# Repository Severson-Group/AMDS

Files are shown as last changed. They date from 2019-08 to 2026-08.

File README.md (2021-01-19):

# Advanced Motor Drive Sensing System (AMDS)

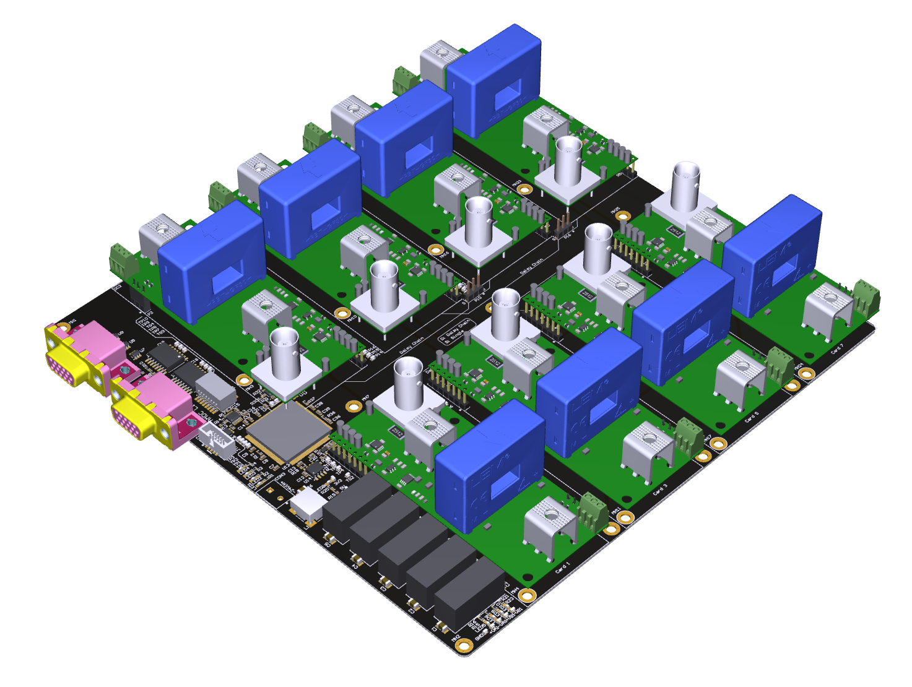
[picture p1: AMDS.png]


The AMDS is a hardware platform for sensing parameters such as currents and voltages in power electronic systems. 
The platform includes:

-  Sensor cards to measure [low voltage](./LowVoltageCard), [high voltage](./HighVoltageCard), and [currents](./CurrentCard).
-  A [mainboard](./Mainboard) that serves as a carrier board for upto 8 sensor cards.
-  SPI interface between the sensor cards and the mainboard.
-  Robust differential IO communication to transmit sensor data to an external controller such as the [AMDC](https://amdc.dev/).

## Documentation
Detailed documentaion for each sensor card and the mainboard are available in the respective folders.

## Repository Structure
Each sensor card and the mainboard have a corresponding folder in the root level of the repository. These folders are organized as follows:

- The `altium` sub-folder contains all files pertaining to schematics / board design in Altium Designer. These files are the latest working copy of the project.

- The `REVyyyymmdd*` sub-folder represents snapshots of the project that were used to produce a physical PCB. These directories contain the Gerber, Drill (Excellon format), Bill of Materials (XLS), and Schematic (PDF) files.

  - `REV` indicates a revision of design for manufacturing
  - `yyyymmdd` indicates the date on which design was frozen
  - `*` (letter) indicates which revision in sequence (A - first, B - second, etc.)
  
- The `docs` sub-folder contains documentation for the PCB.

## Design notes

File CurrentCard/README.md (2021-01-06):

# Current Card

The current card is a daughter card designed for the AMDS platform. This daughtercard plugs into the mainboard which then drives this card.

## Documentation

Documentation about the design of this daughter card is located in the [docs folder.](docs/)

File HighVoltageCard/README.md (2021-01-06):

# High Voltage Card

This folder contains the design files for the high voltage card which serves as a daugherboard for the AMDS mainboard. The high voltage card can measure differential voltages up to +/- 500 V.

The details of the implementation can be found in the [`docs`](docs/) folder.

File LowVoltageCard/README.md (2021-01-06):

# Low Voltage Card

This subfolder houses all the design files for the Low Voltage Card, a daughtercard designed for the AMDS platform. This daughtercard plugs into the mainboard which then drives this board's on-board ADC.

## Documentation

Read about the design of this daughtercard in the [docs folder...](docs/)

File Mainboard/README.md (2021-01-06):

# Mainboard



The mainboard provides a single interface to multiple analog input PCBs (up to 8 daughtercards can be installed). The board features a microcontroller that operates ADCs on each daughter card and presents an isolated, high speed digital interface that can be connected to a digital system control board (this board is designed to connect directly to an expansion port of the [AMDC](https://github.com/severson-group/amdc-hardware)). Design features are implemented to minimize EMI and facilitate operation in an electric motor drive.

The details of the implementation can found in the [`docs/` folder](https://github.com/Severson-Group/SensorCard/blob/Motherboard_REVC/Motherboard/docs/README.md).

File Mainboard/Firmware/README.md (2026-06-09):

# Mainboard Firmware

The "mainboard" is part of the SensorCard platform. It can hold up to eight daughter cards, each of which contain a SPI ADC device. These ADCs are then sampled by the mainboard's MCU. The ADC samples are transmitted back to the AMDC so control algorithms can make use of the extra analog inputs. Several daughter card designs exist:

1. Current sense
2. High Voltage sense (for bus voltage levels)
3. Low Voltage sense (for +/- 10V levels)

This folder houses all the files needed to build the firmware which runs on the MCU on the mainboard PCB.

## Required Tools

To easily build this firmware and load it onto a mainboard, please install the following software on your host PC:

- [STM32CubeIDE](https://www.st.com/en/development-tools/stm32cubeide.html) -- the latest version is fine.

This tool is analogous to the Xilinx SDK tool (for the AMDC). It is effectively the Eclipse IDE but with customizations from ST. You can write all the C code here, compile it, flash the MCU, debug, etc.

## Development Steps

To develop code for STM32 processors:

### Testing / Debugging Code

1. Use the IDE to compile your code and ensure there are no errors.
2. To flash the hardware, plug in a SWD debugger device to your PC + board (highly recommend [`STLINK-V3SET`](https://www.digikey.com/product-detail/en/stmicroelectronics/STLINK-V3SET/497-18216-ND/9636028))
3. Configure a debug session in the IDE
4. Run the debug sessions. This will flash the MCU and start the code (probably breakpoint at `main()`)

For more detailed instructions on programming the AMDS, please refer to the [AMDS Documentation](https://docs.amdc.dev/accessories/amds/index.html).

NOTE: The STM32 devices are typically programmed into non-volatile memory. Therefore, there is no seperate "flashing" step. Every time you upload code, it is permanantely stored on the processor. You can power cycle the device and your code will start running again.

## Mainboard Firmware Design

The mainboard firmware is fairly simple, yet very specialized for the application. Before changing *anything* in the code, make sure you understand how it works. Practically every line of the code is optimized for speed and efficiency! Using a multi-channel logic analyzer / oscilloscope is absolutely required when updating the mainboard firmware to validate code timing. Please refer to the [Firmware Architecture Documentation](https://docs.amdc.dev/accessories/amds/firmware/index.html) for more information.

**Do not blindly change the code.**

## Flashing Firmware to Mainboards with Alternative STM32F745ZG Processors

The firmware project provided in this repository is configured for a mainboard populated with a STM32F**765**ZG processor. This project configuration is incompatible with the alternative STM32F**745**ZG chip that is populated on some mainboard PCBs. Creating a new project targeting the alternative STM32F**745**ZG processor and loading in the provided source files is required. Here's how that's done.

### Create a new STM32 Project
1. Within STM32CubeIDE create a new `STM32 project` targeting the `STM32F745ZG` device with the following settings:
    - Targeted Language: `C`
    - Targeted Binary Type: `Executable`
    - Targeted Project Type: `STM32Cube`

### Replace Source Code
2. Open the file folder location of the newly created project 
3. Navigate to the `\Core\` directory and replace the `\Src` & `\Inc` folders with the ones provided in the AMDS repository
4. Navigate to the `\Drivers\STM32F7xx_HAL_Driver` directory and replace the `\Src` & `\Inc` folders with the ones provided in the AMDS repository
5. Within STM32CubeIDE refresh & build the project, no errors should be present

### Increase Compiler Optimization
6. In the `Project Explorer` pane on the left, right-click on the STM32Cube Project you created, and click on Properties
7. Expand `C/C++ Build` and click `Settings`
8. Find and click on `MCU GCC Compiler` > `Optimization`
9. Select the dropdown next for `Optimization Level` and change to `Optimize more (-O2)`
10. Select `Apply and Close`

### Flash Firmware to Mainboard
11. Select `Debug Configurations` under the `Run` menu at the top
12. Select the `Debugger` tab in the pop-up window
13. Change the `Frequency (kHz)` setting from `Auto` to `140`
14. Select `Apply` 

You are now ready to connect & flash the firmware to the STM32F**745**ZG processor equiped Mainboard!

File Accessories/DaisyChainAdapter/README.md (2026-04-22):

# AMDS Daisy Chain Adapter Board

This subfolder houses all the design files for the daisy chain adapter board used to operate the AMDS in a daisy-chained configuration.

## Documentation

Documentation about the design of this  board can be found in the [docs folder.](docs/)

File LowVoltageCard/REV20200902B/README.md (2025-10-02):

# Low Voltage Card REV20200902B

This folder contains the compiled design outputs for the Low Voltage Card. This includes the schematics, images of the PCB layout, the bill of materials (BOM), and the files needed to order fully populated boards from an online vendor.

## Board Parameters

| Question | Answer |
|---|---|
| Board Size | 3.575" x 1.465" |
| Number of Layers | 2 Layers |
| Double Sided | No |
| Surface Finish | Tin lead |
| Silkscreen | White |
| Material | FR-4, TG150 |
| Board Thickness | 1.6 mm |
| Min Trace Spacing | 0.15 mm (6 mil) |
| Min Hole Size | 0.38 mm (15 mil)|
| Number of Holes | 55 |
| Solder Mask | Black |
| HASL or ENIG | No |
| Finished Copper | 1 oz |

## Assembly Details

| Question | Answer |
|---|---|
| Unique Part Count[^1] | 20 |
| Number of Total Parts[^1] | 52 |
| Total SMT Part Count | 47 |
| Total Through-hole Part Count | 5 |
| Total Mechanical Screws[^2] | 2 |
| Total Mechanical Standoffs[^2] | 2 |
| BGA / QFN | No |

[^1]: This number does not include screws or standoffs. With screws and standoffs included, the unique part count is 22 and total parts is 56. Users are advised to not have their assembly vendor place screws and standoffs.

[^2]: There are screws and standoffs required for mounting this card to the mainboard. For details on what those components are, please refer to the [Main Board](../../Mainboard/REV20200920D/README.md)

## Bill of Materials
The [Bill of Materials (BOM)](low-voltage-card-bom.csv) contains components for 1 board. If users of this repo discover that any components are unavailable, please maintain an `alternate-components.md` file in this folder that lists approved alternates.

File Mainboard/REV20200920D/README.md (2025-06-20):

# AMDS REV20200920D

This folder contains the compiled design outputs for AMDS REV D. This includes the schematics, images of the PCB layout, the bill of materials (BOM), and the files needed to order fully populated boards from an online vendor.

## Board Parameters

| Question | Answer |
|---|---|
| Board Size | 8" x 8" |
| Number of Layers | 4 Layers |
| Double Sided | No |
| Surface Finish | Tin lead |
| Silkscreen | White |
| Material | FR-4, TG150 |
| Board Thickness | 1.6 mm |
| Min Trace Spacing | 0.15 mm (6 mil) |
| Min Hole Size | 0.35 mm (14 mil)|
| Number of Holes | 569 |
| Solder Mask | Black |
| HASL or ENIG | No |
| Finished Copper | 1 oz |

## Assembly Details

| Question | Answer |
|---|---|
| Unique Part Count[^1] | 42 |
| Number of Total Parts[^1] | 199 |
| Total SMT Part Count | 146 |
| Total Through-hole Part Count | 53 |
| Total Mechanical Screws[^2] | 43 |
| Total Mechanical Standoffs[^3] | 27 |
| BGA / QFN | No |

[^1]: This number does not include screws or standoffs. With screws and standoffs included, the unique part count is 45 and total parts is 269. Users are advised to not have their assembly vendor place screws and standoffs.

[^2]: There are a total of 43 screws per board, where 11 screws will be used for the mainboard mounting holes, and 32 screws will be used for mounting the 8 sensor cards.

[^3]: There are a total of 27 standoffs per board, where 11 standoffs will be used for the mainboard mounting holes, and 16 standoffs will be used for mounting all the 8 sensor cards.

## Bill of Materials
The [Bill of Materials (BOM)](mainboard-bom.csv) contains components for 1 board. If users of this repo discover that any components are unvailable, please maintain an `alternate-components.md` file in this folder that lists approved alternates. 

Note that several resistors are indicated with a value of `DNP` (do not populate). These are components that should not be soldered onto the board in standard builds to avoid ground loops and allow for daisy chain operation[^4].

## Sensor Card Mounting
The [Bill of Materials (BOM)](mainboard-bom.csv) and [Schematic](mainboard-sch.pdf)[^5] contain the screws and standoffs required to mount 8 sensor cards to 1 board.

[^4]: An audit of the DNP components is discussed in [this GitHub issue](https://github.com/Severson-Group/AMDS/issues/63).

[^5]: Note that the large amount of mounting hardware on this schematic means that the default export PDF from Altium results in a large file size. For this reason, developers are advised to use Adobe to compress the schematic file before committing to the repo. The `Low` compression setting is recommended.

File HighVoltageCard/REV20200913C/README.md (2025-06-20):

# High Voltage Card REV20200913C

This folder contains the compiled design outputs for the High Voltage Card. This includes the schematics, images of the PCB layout, the bill of materials (BOM), and the files needed to order fully populated boards from an online vendor.

## Board Parameters

| Question | Answer |
|---|---|
| Board Size | 3.57" x 1.46" |
| Number of Layers | 2 Layers |
| Double Sided | No |
| Surface Finish | Tin lead |
| Silkscreen | White |
| Material | FR-4, TG150 |
| Board Thickness | 1.6 mm |
| Min Trace Spacing | 0.15 mm (6 mil) |
| Min Hole Size | 0.40 mm (16 mil)|
| Number of Holes | 54 |
| Solder Mask | Black |
| HASL or ENIG | No |
| Finished Copper | 1 oz |

## Assembly Details

| Question | Answer |
|---|---|
| Unique Part Count[^1] | 23 |
| Number of Total Parts[^1] | 42 |
| Total SMT Part Count | 27 |
| Total Through-hole Part Count | 15 |
| Total Mechanical Screws[^2] | 2 |
| Total Mechanical Standoffs[^2] | 2 |
| BGA / QFN | No |

## Bill of Materials
The [Bill of Materials (BOM)](high-voltage-sensor-bom.csv) contains components for 1 board. If users of this repo discover that any components are unavailable, please maintain an `alternate-components.md` file in this folder that lists approved alternates.

[^1]: This number does not include screws or standoffs. With screws and standoffs included, the unique part count is 25 and total parts is 46. Users are advised to not have their assembly vendor place screws and standoffs.

[^2]: There are screws and standoffs required for mounting this card to the mainboard. For details on what those components are, please refer to the [Main Board](../../Mainboard/REV20200920D/README.md)

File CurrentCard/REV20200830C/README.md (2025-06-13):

# Current Card REV20200830C

This folder contains the compiled design outputs for the Current Card. This includes the schematics, images of the PCB layout, the bill of materials (BOM), and the files needed to order fully populated boards from an online vendor.

## Board Parameters

| Question | Answer |
|---|---|
| Board Size | 3.58" x 1.47" |
| Number of Layers | 2 Layers |
| Double Sided | No |
| Surface Finish | Tin lead |
| Silkscreen | White |
| Material | FR-4, TG150 |
| Board Thickness | 1.6 mm |
| Min Trace Spacing | 0.15 mm (6 mil) |
| Min Hole Size | 0.40 mm (16 mil)|
| Number of Holes | 58 |
| Solder Mask | Black |
| HASL or ENIG | No |
| Finished Copper | 1 oz |

## Assembly Details

| Question | Answer |
|---|---|
| Unique Part Count[^1] | 21 |
| Number of Total Parts[^1] | 41 |
| Total SMT Part Count | 27 |
| Total Through-hole Part Count | 14 |
| Total Mechanical Screws[^2] | 4 |
| Total Mechanical Standoffs[^2] | 2 |
| BGA / QFN | No |

## Bill of Materials
The [Bill of Materials (BOM)](current-sensor-bom.csv) contains components for 1 board. If users of this repo discover that any components are unavailable, please maintain an `alternate-components.md` file in this folder that lists approved alternates.

[^1]: This number does not include screws or standoffs. With screws and standoffs included, the unique part count is 23 and total parts is 45. Users are advised to not have their assembly vendor place screws and standoffs.

[^2]: There are screws and standoffs required for mounting this card to the mainboard. For details on what those components are, please refer to the [Main Board](../../Mainboard/REV20200920D/README.md)

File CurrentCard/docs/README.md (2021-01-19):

# Current Card

This document describes the design considerations and implementation details for the current card. 
A block diagram is presented and each component is discussed in detail. Specifications of each component are provided based on the datasheet.

## Relevant Hardware Versions

REV C

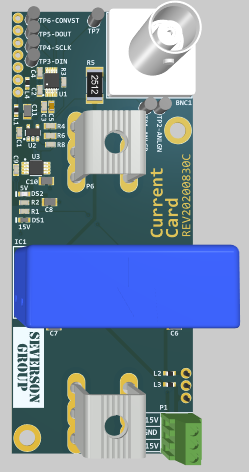
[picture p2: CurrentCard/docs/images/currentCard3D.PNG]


## Design Requirements and Considerations

The current measurement card was designed to the following specifications:

1. Current measurement range of +/- 55A (rms)
2. Noise immunity
3. Quick adjustment of the sensing range
4. High sensor bandwidth
5. SPI output to interface with the sensor motherboard

## Block Diagram
The high level block diagram of the current sensor card is shown below:



### Current Sensor
LEM LA 55-P current sensor is selected for this design, as it is the only sensor available from LEM with an open aperture and PC pins that can measure +/-55A. 
The open aperture was a requirement as it allows for the range to be easily scaled down just by adding turns to the primary. 
The LA 55-P is a closed loop compensated hall effect transducer that has an accuracy of +/-0.65% and linearity of <0.15% which is quite good compared to other sensors from LEM. 
It has an excellent bandwidth of 200khz and a low impedance current output that is inherently more immune to noise than a high impedance voltage output. 

### Burden Resistor (_R_<sub>_BURDEN_</sub>)
A burden resistor (`R5`) is used to convert the current output of the sensor to a voltage. For a sensing range of 70A, the burden resistance, _R_<sub>_BURDEN_</sub> was calculated using the following equation

_V_<sub>_BURDEN_</sub>  = _I_<sub>_PRIMARY_</sub>(_N_<sub>2</sub>/_N_<sub>1</sub>)_R_<sub>_BURDEN_</sub>

_R_<sub>_BURDEN_</sub>  = (10 V/70 A)*(1000/1) = 143Ω 

The LA 55-P datasheet specifies the burden resistor value must be between 135Ω and 155Ω so a 150Ω resistor was selected.

### Current Sensor Gain
The LA 55P has a conversion ratio of _N_<sub>1</sub>:_N_<sub>2</sub> = 1:1000, where _N_<sub>1</sub> is the primary turns (user configurable) and _N_<sub>2</sub> is the secondary turns. With the chosen _R_<sub>_BURDEN_</sub> and _N_<sub>1</sub> = 1, the current sense circuitry has a current - voltage gain of 1/7 [V/A]. 
To sense lower current, multiple number of primary turns can be added, without the need to modify any other parts of the circuit. As an example, to sense currents in the range of +/- 7 A, _N_<sub>1</sub> = 10 can be used, without modifying rest of the circuit.

### Op Amp Stage
The voltage across the burden resistor is a bipolar signal (voltage span includes both positive and negative voltages).
A non-inverting level translation circuit is designed using Op Amps as shown here:



This circuit is used to translate the voltage across the burden resistor, which is bipolar, to the ADC input range of 0-4.5V. The resistor values can be calculated analytically. However, the algebra gets quite complicated. Hence it was computed using TI analog engineer's calculator. 

**Note:** As the op-amp output voltage approaches the supply rails, it tends to distort and behave nonlinearly so the output voltage is limited to actually be 0.2V to 4.5V

### Voltage Reference (LDO)
The voltage reference, _V_<sub>_REF_</sub> is needed for the ADC. As 5V is readily available, and the LDO will have a minimum drop out voltage,  _V_<sub>_REF_</sub> = 4.5V was chosen. The LDO selected was `REF5045` from Texas Instruments, which can take a 5V input and provide a 4.5V reference output. This has an accuracy of 0.1% and low noise of 3μVpp/V.

### First Order Anti-Aliasing Filter
A first order RC filter is implemented on the output of the op amp circuit. The cutoff frequency was set at 48kHz and the following equations was used for the computation:

_f_<sub>c</sub> = 1 / (2 π _RC_)

**Note:** The cutoff frequency can easily be changed by swapping out `R3`.

### Analog to Digital Converter
A single-ended ADC was selected. The ADC used is the Texas Instruments ADS8860. It is pseudo-differential input, SPI output, SAR ADC. 
The maximum data throughput for a single chip is 1 MSPS but decreases by a factor of N for N devices in the daisy-chain. 
The input voltage range is 0-4.5V. The positive input pin of the ADC `AINP` is connected to the output of the low pass filter, and the negative input pin `AINN` is connected to `GND`.

**Note:** The different stages of the current sensor card described above convert the input current into a voltage in the range of 0.2V - 4.5V. Therefore, 0 input current corresponds to 2.35V at the ADC input. The positive peak corresponds to 4.5V and the negative peak corresponds to 0.2V.

### Connectors
- There are two screw terminals `P5` and `P6` to connect the conductor in which the current is to be measured
- A screw terminal block `P1` is used to connect the +-15V supply for the current sensor
- A BNC terminal is available to directly measure the output across the burden resistor _R_<sub>_BURDEN_</sub>

### Footprints
A user may want to change some of the passive components based on the range required and the RC filter cutoff frequency desired. The footprints of passive components that may need to be replaced i.e, the burden resistor (`R5`), the resistors in the Op Amp stage, and the RC filter components is provided here for quick reference. Note that these footprints are imperial codes and **not metric codes**.

| Component | Footprint |
| ---- | ----- |
| R3 |  0603|
| R4 | 0603 |
| R5 | 2512 |
| R6 | 0603 |
| R8 | 0603 |
| C5 | 0603 |

## Datasheets
- [Current Sensor](../datasheets/LA55P_Current%20Sensor.pdf)
- [Op Amp](../datasheets/OPA320_OpAmp.pdf)
- [Voltage Reference (LDO)](../datasheets/REF5045_LDO.pdf)
- [Analog to Digital Converter](../datasheets/ADS_8860_ADC.pdf)

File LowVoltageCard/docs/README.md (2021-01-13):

# Low Voltage Card

This document describes the design considerations and implementation details for the low voltage card, which serves as a daughtercard for the AMDS mainboard.

## Relevant Hardware Versions

- REV A
- REV B

## Design Requirements and Considerations

The analog input card was designed to the following specifications:

1. Analog input signal of +/- 10V
2. Truly differential input
3. High common-mode rejection ratio
4. ADC has various pin-compatible versions available (different sampling rates)

Since these requirements very closely mirror the analog inputs on the AMDC, a similar design is used. The reader can learn about the AMDC analog inputs by reading [its documentation](https://github.com/Severson-Group/AMDC-Hardware/blob/develop/docs/Analog.md). The same front-end analog conditioning circuitry is used. However, while the ADC is still a differential input device (like the AMDC), it is a different part. This analog input board has a single-channel 16-bit ADC that accepts differential inputs. The digital interface is standard SPI.

Various ADCs are available which are pin-compatible to the part designed into the PCB. This means that the user can select which one they want when they assemble the boards. The ADCs offer the same specs, but vary on the sample rate. More expensive ADCs provide a higher sample rate.

### Pin Compatible ADCs

The default ADC is **bolded** below, but any of the follow ADCs work with the design.

- 100 kSPS: ADS8867
- **400 kSPS: ADS8865**
- 680 kSPS: ADS8863
- 1000 kSPS: ADS8861

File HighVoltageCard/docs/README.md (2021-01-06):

# High Voltage Card

This document describes the design consideration and implementation details for the high voltage card, which serves as a daughter card for the AMDS mainboard.
A block diagram is presented and each component is discussed in detail. Specifications of each component are provided based on the datasheet.

## Relevant Hardware Versions

REV C

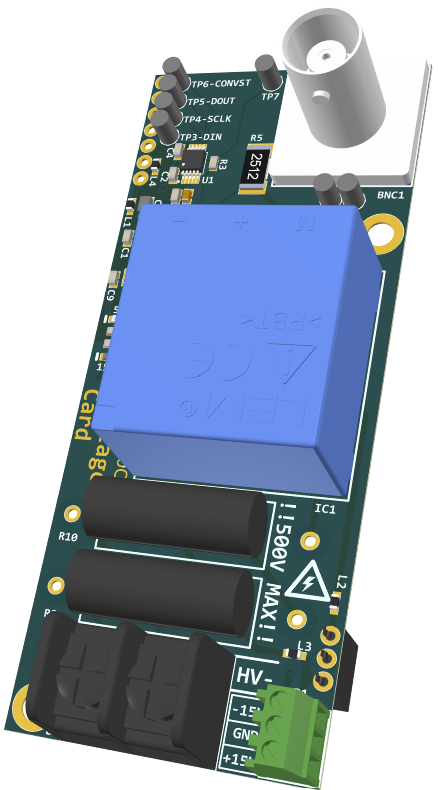
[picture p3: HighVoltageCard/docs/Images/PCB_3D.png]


## Design Requirements and Considerations

The voltage measurement card was designed to the following specifications:

1. Voltage measurement range of +/- 500V
2. SPI output to interface with the AMDS mainboard
3. +/- 10V BNC output

## Block Diagram
The high level block diagram of the voltage sensor card is shown below:



### Voltage Sensor
The voltage sensor selected is the LEM LV 25-P, which basically senses the current proportional to the voltage to be measured. The sensor has a nominal input current of 10mA, an accuracy of 0.8%, and a linearity error under 0.2%. Two 25kΩ, 5W input resistors `R9` and `R10` are used to get a differential voltage measuring range up to +/- 500V. 
The sensor output is a current in the range of +/-25mA. 

To vary the voltage measurement range, the input resistors `R9` and `R10` can be suitably varied such that the input current to the sensor is limited to 10mA.
For example, to get a voltage measurement range of 250V, the resistor values of `R9` and `R10` should be reduced to 12.5kΩ each.

### Burden Resistor
The output of the voltage sensor is a current in the range of +/-25mA, which is converted to a voltage in the desired range using a burden resistor `R5`. The present implementation converts the sensor output current to a +/-8.75V signal using a burden resistor of 350Ω.

### Level shift stage
The voltage across the burden resistor is a bipolar signal (voltage span includes both positive and negative voltages). A non-inverting level translation circuit is designed using Op Amps as shown here:



This circuit is used to translate the voltage across the burden resistor, which is bipolar, to the ADC input range of 0-4.5V. The resistor values can be calculated analytically using the following formula:



The algebra can get quite complicated when solving it analytically. So the resistor values were computed to be R<sub>a</sub> = 10kΩ, R<sub>b</sub> = 8.45kΩ, and R<sub>c</sub> = 4.64kΩ using the TI analog engineer's calculator.

**Note:** As the op-amp output voltage approaches the supply rails, it tends to distort and behave nonlinearly so the output voltage is limited to actually be 0.2V to 4.5V.

### RC Filter
A first order RC filter is implemented on the output of the op amp circuit. The cutoff frequency was set at 48kHz and the following equations was used for the computation:

_f_<sub>c</sub> = 1 / (2 π _RC_)

**Note:** The cutoff frequency can easily be changed by swapping out `R3`.

### Analog to Digital Converter
To increase noise immunity, the card has an inbuilt Analog to Digital Conversion (ADC) IC. The ADC used is the Texas Instruments ADS8860. It is pseudo-differential input, SPI output, SAR ADC. The maximum data throughput for a single chip is 1 MSPS but decreases by a factor of N for N devices in the daisy-chain. 

The different stages of the voltage sensor card described above convert the input voltage, to a voltage in the range of 0.2V - 4.5V. The voltage at the ADC input V<sub>ADC</sub> is related to the sensor card input voltage V<sub>IN</sub> as follows:



where R<sub>BURDEN</sub> is the burden resistor, R<sub>IN</sub> is the input resistance, and K<sub>N</sub> is the sensor conversion ratio from the datasheet. For LV-25P, the data sheet lists K<sub>N</sub> = 2500:1000.

For the current design, 0V input voltage corresponds to 2.35V at the ADC input. The positive peak corresponds to 4.5V and the negative peak corresponds to 0.2V.

### Connectors
- The HV terminal block `B1` with screw connectors is used to connect the HV terminals across which voltage has to be measured. 
- A screw terminal block `P1` is used to connect the +-15V supply for the current sensor
- A BNC terminal is available to directly measure the output across the burden resistor.

### Footprints
A user may want to change some of the passive components based on the range required and the RC filter cutoff frequency desired. The footprints of passive components that may need to be replaced i.e, the burden resistor (`R5`), the resistors in the Op Amp stage, and the RC filter components is provided here for quick reference. Note that these footprints are imperial codes and **not metric codes**.

| Component | Function | Footprint | 
| ---- | ----- |---|
| R3 | RC filter resistor | 0603| 
| R4 | Level shift stage|0603 |
| R5 | Burdern resistor |2512 |
| R6 |Level shift stage |0603 |
| R8 |Level shift stage |0603 |
| R9 | Input resistor|Through hole|
| R10| Input resistor |Through hole|
| C5 | RC filter capacitor |0603 |

### Datasheets

- [Voltage sensor](../datasheets/LV25P_Sensor.pdf)
- [Op Amp](../datasheets/OPA320_OpAmp.pdf)
- [Voltage Reference (LDO)](../datasheets/REF5045_LDO.pdf)
- [ADC](../datasheets/ADS_8860_ADC.pdf)

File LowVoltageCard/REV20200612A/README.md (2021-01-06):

# Analog Sensor Card REV20200612A

This folder contains the compiled design outputs for the Analog Sensor Card REV D (design frozen on June 12, 2020). This includes the schematics, images of the PCB layout, the bill of materials (BOM), and the files needed to order boards from fab houses (gerbers).

## PCB Properties

| Question | Answer |
|---|---|
| Board Size (H x W) | 3.575" x 1.465"  |
| Numer of Layers | 2 |
| Number of Holes | 55 |
| Number of Slots/Cutouts | 0 |
| Surface Finish | Tin Lead (HASL)  |
| Silkscreen | Both Sides |
| Copper Weight | 1oz |
| Trace Width / Spacing | 6/6mil |
| Min Drill | 13mil |

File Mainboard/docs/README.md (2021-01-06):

# Mainboard

This document describes the design consideration, implementation details, and board interface details for the sensor mainboard. A block diagram is presented and each component is discussed in detail.

## Relevant Hardware Versions

REVD

## Application / Purpose

The mainboard is specifically designed to interface directly to the isoSPI connector of [AMDC REVD](https://github.com/Severson-Group/AMDC-Hardware).

## Features

- Can connect up to 8 sensor daughter cards.
- Can communicate with an external controller (like AMDC). An external controller can obtain the measurement results and also is allowed to control the digital conversion process.
- Robust differential IO communication is used to transmit sensor data to an external controller.
- High throughput of up to 1 MSPS (depending on ADC device on daughter cards).

## Block Diagram and SPI Connection Configuration

The eight daughter cards (DC) transmit data to the STM32 MCU using standard SPI protocol. The daughter cards are grouped into four pairs of daisy chain connections. See the following block diagram.



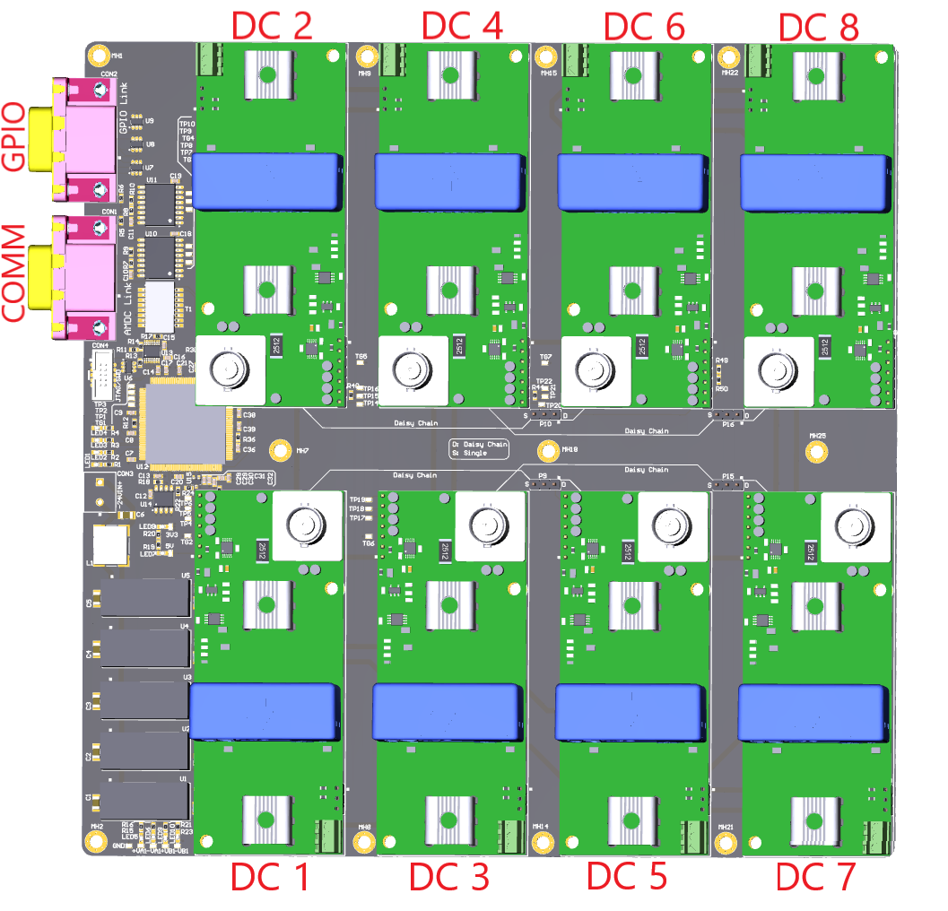
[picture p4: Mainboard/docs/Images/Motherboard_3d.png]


The daughter cards can be connected in daisy chain pair configuration (D) or single SPI configuration (S). The daisy chain configuration will have a throughput of 500 kSPS. If the number of daughter cards is less than or equal to four, then a single SPI configuration can be used to get higher throughput. This single SPI configuration will have a throughput of 1 MSPS. The configuration can be changed using jumpers (P9, P10, P15, P16) as shown in the following figure.

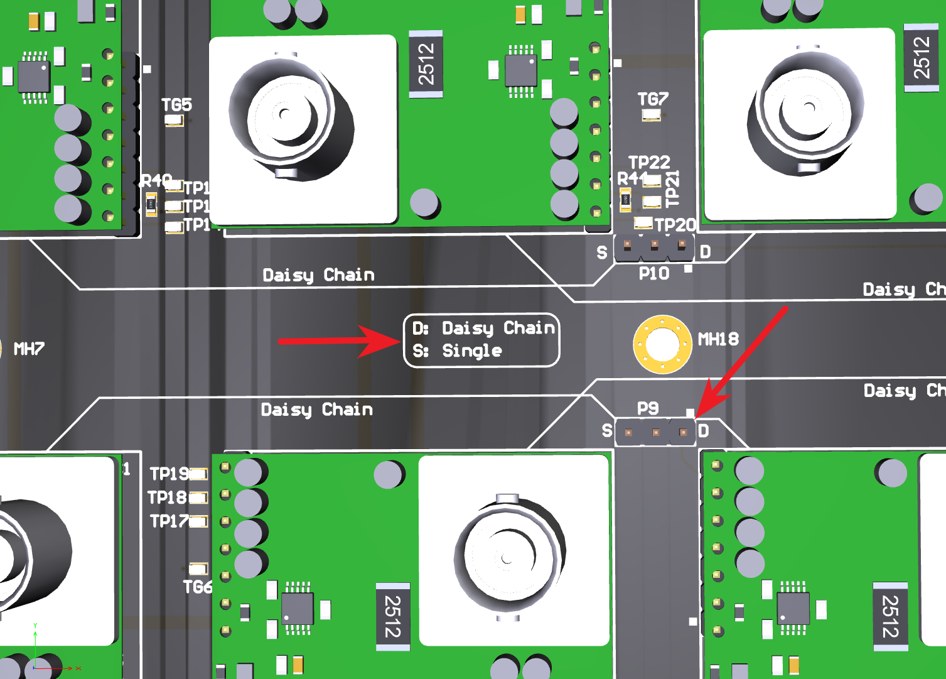
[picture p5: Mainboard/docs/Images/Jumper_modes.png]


## External Connections

There are two interfacing DB-15 connectors on the measurement board. The first connector is used for interfacing with the external controller via isoSPI and differential IO communication. The second connector is intended as an expansion port connection, which is connected to the GPIO port of the MCU.

### DB15 Connector 1: IsoSPI and Differential IO 

| Pin number | Signal name | Voltage level | Protocol |
|---|---|---|---|
| 1 | 5V_IN | 5V | - |
| 2 | D2_I_P | 5V | Differential IO |
| 3 | D2_I_N | 5V | Differential IO |
| 4 | D3_I_P | 5V | Differential IO |
| 5 | D3_I_N | 5V | Differential IO |
| 6 | NC | - | - |
| 7 | isoSPI2_P | 5V | IsoSPI |
| 8 | isoSPI2_N | 5V | IsoSPI |
| 9 | isoSPI3_P | 5V | IsoSPI |
| 10 | isoSPI3_N | 5V | IsoSPI |
| 11 | GND | - | - |
| 12 | D2_O_P | 5V | Differential IO |
| 13 | D2_O_N | 5V | Differential IO |
| 14 | D3_O_P | 5V | Differential IO |
| 15 | D3_O_N | 5V | Differential IO |

### DB15 Connector 2: GPIO

| Pin number | Signal name | Voltage level |
|---|---|---|
| 1 | 3V3 | 3.3V |
| 2 | GPIO_1 | 3.3V |
| 3 | GPIO_2 | 3.3V |
| 4 | GPIO_3 | 3.3V |
| 5 | GPIO_4 | 3.3V |
| 6 | GPIO_5 | 3.3V |
| 7 | GPIO_6 | 3.3V |
| 8 | GPIO_7 | 3.3V |
| 9 | GPIO_8 | 3.3V |
| 10 | GPIO_9 | 3.3V |
| 11 | GPIO_10 | 3.3V |
| 12 | GPIO_11 | 3.3V |
| 13 | GPIO_12 | 3.3V |
| 14 | GND | - |
| 15 | GND | - |

Implementation details of [IsoSPI](#IsoSPI-Communication-Interface) and [Differential IO](#Differential-IO-Isolated-Transceiver) is described later in the document.

## Systems on Board

Per the block diagram above, the mainboard is made of several systems, as explained below.

### STM32F7 Microcontroller

STM32F7 microcontroller is used as an interface between the daughter card and an external controller. This MCU has a core ARM 32-bit Cortex M7 CPU. This IC can operate at a supply voltage of 1.7 V to 3.6 V. JTAG / SWD interface is used for debugging and programming the MCU. It has 6 SPIs which is used for daughter card and AMDC isoSPI interfaces. The maximum speed of the MCU SPI interface is 54 Mbps. It has 4 USART with a maximum baud rate of 26 Mbps, which are used to transmit daughter card data to the AMDC. GPIO pins of the MCU can be accessed using GPIO connector. More information on this MCU can be found [here](https://www.st.com/content/ccc/resource/technical/document/datasheet/group3/c5/37/9c/1d/a6/09/4e/1a/DM00273119/files/DM00273119.pdf/jcr:content/translations/en.DM002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).

### Differential IO Isolated Transceiver

The MCU transmits sensor data via USART communication. These USART signals are converted to differential IO using differential transceiver [ISO3086T](https://www.ti.com/lit/ds/symlink/iso3086t.pdf?HQS=TI-null-null-digikeymode-df-pf-null-wwe&ts=1596613093516). Differential IO has the ability to communicate over long distances and at faster communication rate compared to standard USART. This IC has an in-built isolation barrier. A signaling rate of up to 20 Mbps is obtained from this IC. The operating voltage is provided in the following table.

| Parameter | Conditions | MIN |  MAX  |
|---|---|---|---|
| Supply voltage VCC2 (Bus-side) | | 4.5 V | 5.5 V |
| IO supply voltage VCC1 (UART side) | 3.3V operation  | 3 V | 3.6 V |
| IO supply voltage VCC1 (UART side) | 5V operation | 4.5 V |  5 V  |

The maximum supply current consumed by the IC including to drive currents for differential lines is 60 mA, which corresponds to 300 mW for 5 V supply. 

### IsoSPI Communication Interface

The isoSPI communication interface is implemented using [LTC6820](https://www.analog.com/media/en/technical-documentation/data-sheets/LTC6820.pdf). This IC provides a bi-directional interface between standard SPI signals and differential pulses. The operating conditions are provided in the following table.

| Parameter | Conditions | MIN |  MAX  |
|---|---|---|---|
| Supply voltage VDD (Differential side)| | 2.7 V | 5.5 V |
| IO supply voltage VDDS (SPI side) | | 1.7 V | 5.5 V |
| High-level input voltage |VDDS = 2.7V to 5V  | 0.7 VDDS| VDDS  |
| High-level input voltage |VDDS = 1.7V to 2.7V| 0.8 VDDS| VDDS  |
| Low-level input voltage |VDDS = 2.7V to 5V  | 0 | 0.3 VDDS  |
| Low-level input voltage |VDDS = 1.7V to 2.7V| 0 | 0.2 VDDS  |

This IC can operate at a maximum SPI communication speed of 1 Mbps. The bias resistors (`RB1` and `RB2`) are used to adjust the drive currents to the differential lines. These resistors are selected such that the drive currents are set at 10 mA. These resistors are on the schematic, see the following figure.

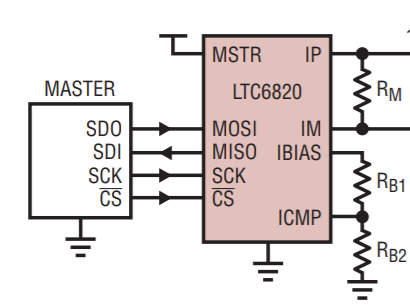
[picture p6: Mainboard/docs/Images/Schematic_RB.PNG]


The maximum supply current consumed by the IC including to drive currents for differential lines is 17 mA, which corresponds to 85 mW for 5 V supply.

### IsoSPI Isolation Transformer

A transformer is required for implementing isoSPI. This will provide an isolation barrier to the differential SPI signals. This is implemented by adding pulse transformer HX1188NLT, which has 1:1 turns ratio. More information on the pulse transformer is found in the [datasheet](https://media.digikey.com/pdf/Data%20Sheets/Pulse%20PDFs/10_100BASE-T%20Single%20Port%20SMD%20Magnetics_Rev2008.pdf).

## Daugter Card Interface

In order to design a daugter card, the interface information provided in this section will be useful. Each daughter card slot has two headers, where the daughter card can be plugged in. See the following figure.

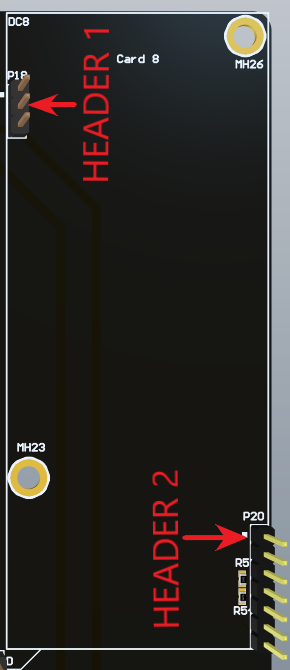
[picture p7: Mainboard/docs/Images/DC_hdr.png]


One header is used to supply power to the cards and the other header is used for SPI interface. 

### Header 1: Power Supply

| Pin number | Signal name |
|---|---|
| 1 | +15V |
| 2 | GND |
| 3 | -15V |

### Header 2: SPI interface

| Pin number | Signal name |
|---|---|
| 1 | 5V |
| 2 | 3V3 |
| 3 | GND |
| 4 | DIN (ADC IN, MOSI) |
| 5 | DOUT (ADC OUT, MISO) |
| 6 | SCLK |
| 7 | CONVST (Conversion start) |

For information regarding the placement of the headers, refer to the [mainboard PCB](../altium/SensorMotherBoard.PcbDoc). For more information on designing a daughter card, refer the [low voltage card documentation](https://github.com/Severson-Group/SensorCard/tree/develop/AnalogCard/docs).

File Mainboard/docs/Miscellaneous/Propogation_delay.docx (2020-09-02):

# Propagation delay calculation

- Board: Sensor motherboard
- Revision: REV20200407C
- Designer: Ashad Farhan

On PCB trace, the propagation delay is given by:

t_(pd) =85√(E_r) picosecond/inches

Where E_r (effective dielectric constant for FR4) is 4 for stripline (inner layer).

The maximum trace length is in the inner layer (layer 3) and the length of the trace is 7.08 inches, so the propagation delay for this trace is 1.161 nanoseconds.

The speed of this SPI trace is 54 Mhz (18.5 ns), so the skew of the trace will be +/- 6.5%

References

[1] https://www.analog.com/media/en/training-seminars/tutorials/MT-094.pdf

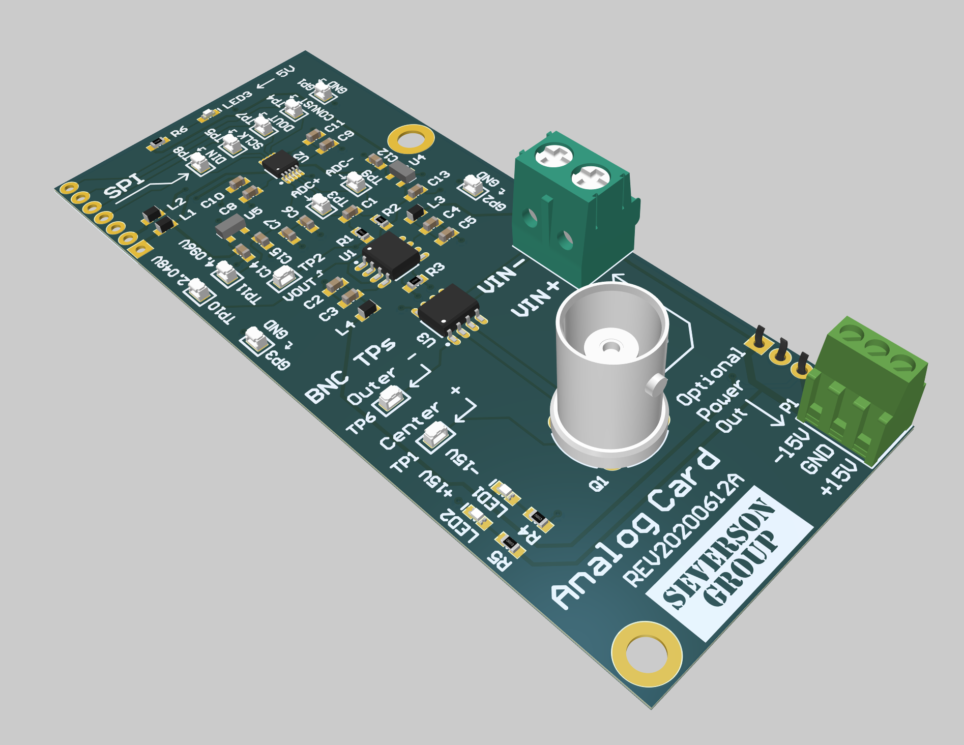
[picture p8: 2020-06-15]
LowVoltageCard/REV20200612A/AnalogSensorCard_PCB_3D.png

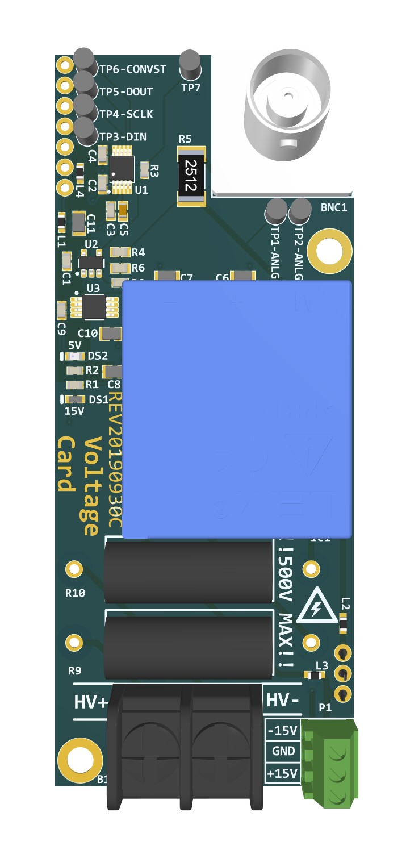
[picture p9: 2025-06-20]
HighVoltageCard/REV20200913C/pcb-3d.jpg

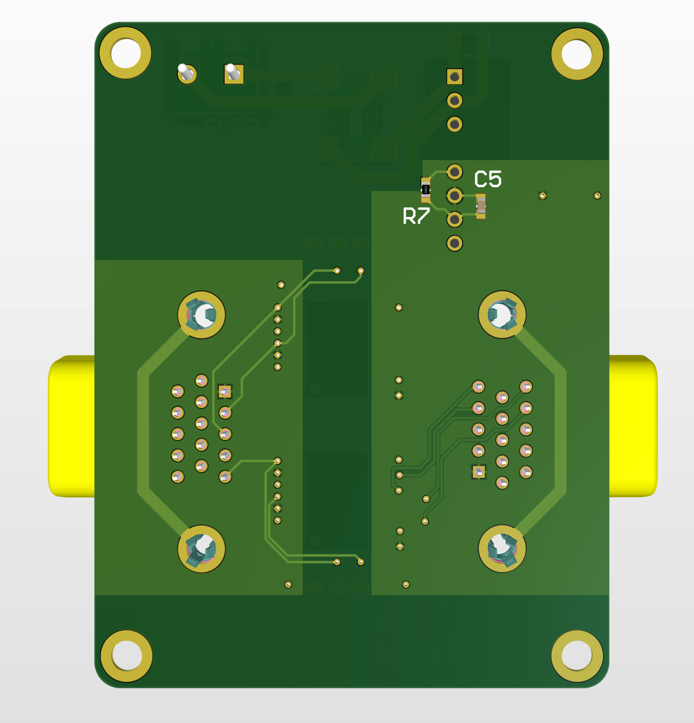
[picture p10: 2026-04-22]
Accessories/DaisyChainAdapter/REV20260129A/pcb-3d-bottom.png

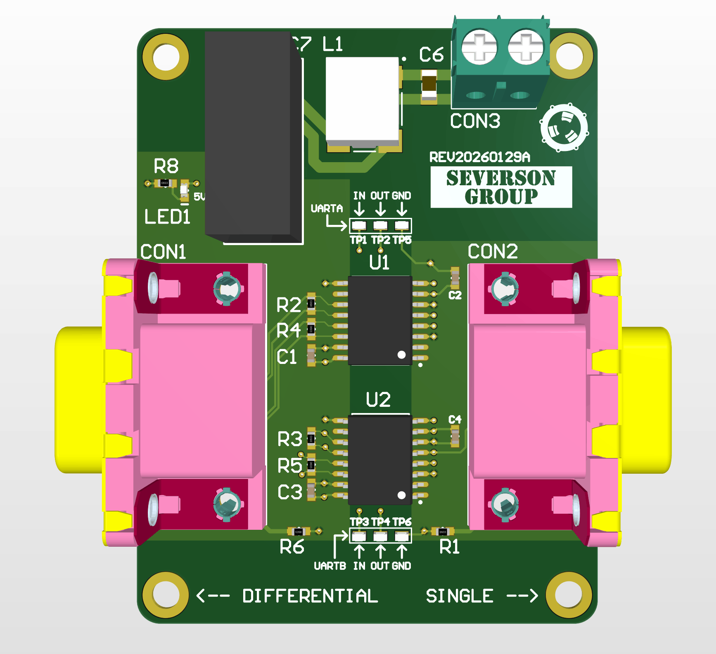
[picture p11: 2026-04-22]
Accessories/DaisyChainAdapter/REV20260129A/pcb-3d-top.png

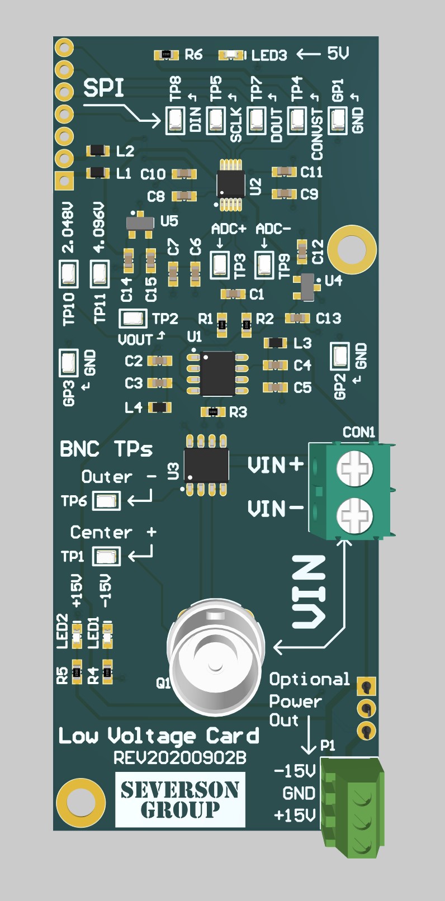
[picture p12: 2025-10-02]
LowVoltageCard/REV20200902B/pcb-3d.jpg

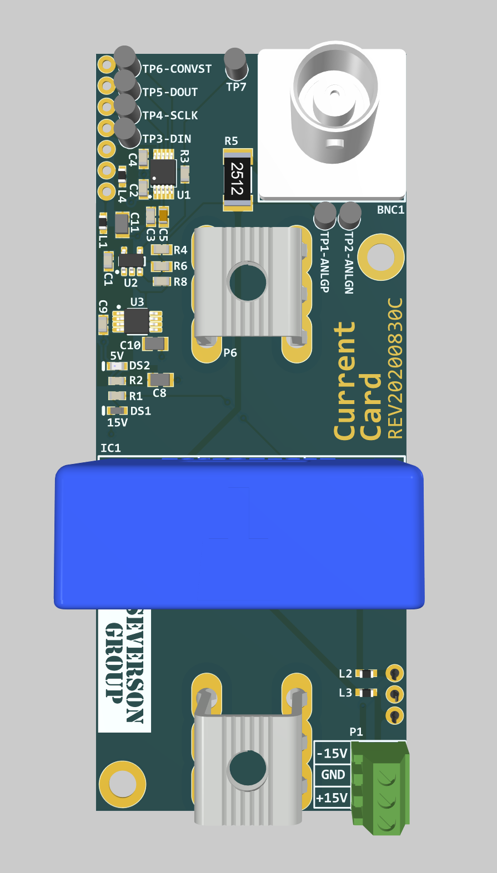
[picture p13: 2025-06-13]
CurrentCard/REV20200830C/pcb-3d.PNG

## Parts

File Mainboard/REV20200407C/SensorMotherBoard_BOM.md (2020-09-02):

# SensorMotherBoard REVC BOM

| Index | Quantity | Part Number | Manufacturer Part Number | Description | Customer Reference | Available | Backorder | Unit Price | Extended Price USD |
| ----- | --- | --- | --- | --- | --- | --- | --- | --- | --- |
| 1 | 360 | A106145CT-ND | RCU-0C | PC TEST POINT NATURAL | +VA1, +VB1, 3V3, 5V, GND1, TG1, TG2, TG3, TG4, T | 360 | 0 | 0.14032 | 50.52 |
| 2 | 60 | 445-11734-1-ND | C3216JB1H685K160AB | CAP CER 6.8UF 50V JB 1206 | C1, C2, C3, C4, C5, C6 | 60 | 0 | 0.822 | 49.32 |
| 3 | 300 | 311-1343-1-ND | CC0603ZRY5V9BB104 | CAP CER 0.1UF 50V Y5V 0603 | C7, C8, C9, C10, C11, C12, C13, C14, C15, C16, C | 300 | 0 | 0.0237 | 7.11 |
| 4 | 20 | 609-5180-ND | ICD15S13E4GV00LF | CONN DSUB HD RCPT 15POS R/A SLDR | CON1, CON2 | 20 | 0 | 1.181 | 23.62 |
| 5 | 10 | 277-1667-ND | 1935161 | TERM BLK 2POS SIDE ENTRY 5MM PCB | CON3 | 10 | 0 | 0.411 | 4.11 |
| 6 | 10 | 609-6533-ND | 20021521-00010D4LF | CONN HEADER SMD 10POS 1.27MM | CON4 | 10 | 0 | 1.317 | 13.17 |
| 7 | 10 | 732-2215-6-ND | 744273801 | CMC 9UH 3.5A 2LN 800 OHM SMD | L1 | 10 | 0 | 3.825 | 38.25 |
| 8 | 10 | 160-1647-1-ND | LTST-C191TBKT | LED BLUE CLEAR CHIP SMD | LED1 | 10 | 0 | 0.342 | 3.42 |
| 9 | 10 | 160-1478-1-ND | LTST-S270KGKT | LED GREEN CLEAR CHIP SMD R/A | LED2 | 10 | 0 | 0.179 | 1.79 |
| 10 | 30 | 160-1448-6-ND | LTST-C191KSKT | LED YELLOW CLEAR SMD | LED3, LED6, LED10 | 30 | 0 | 0.43733 | 13.12 |
| 11 | 80 | 732-5320-ND | 61300711121 | CONN HEADER VERT 7POS 2.54MM | P1, P4, P5, P8, P11, P14, P17, P20 | 80 | 0 | 0.219 | 17.52 |
| 12 | 120 | 732-5316-ND | 61300311121 | CONN HEADER VERT 3POS 2.54MM | P2, P3, P6, P7, P9, P10, P12, P13, P15, P16, P18 | 120 | 0 | 0.067 | 8.04 |
| 13 | 250 | P0.0GDKR-ND | ERJ-3GEY0R00V | RES SMD 0 OHM JUMPER 1/10W 0603  | R5, R6, R12, R24, R34, R36, R37, R45, R50, R51,  | 250 | 0 | 0.0402 | 10.05 |
| 14 | 60 | 311-0.0ERCT-ND | RC1206JR-070RL | RES SMD 0 OHM JUMPER 1/4W 1206 | R38, R39, R42, R43, R47, R48 | 60 | 0 | 0.0338 | 2.03 |
| 15 | 10 | 553-1536-1-ND | HX1188NLT | XFRMR MAGNETIC 1PORT 1:1 10/100  | T1 | 10 | 0 | 3.929 | 39.29 |
| 16 | 40 | 945-2987-ND | RS6-2415S | DC DC CONVERTER 15V 6W | U1, U2, U3, U4 | 40 | 0 | 14.176 | 567.04 |
| 17 | 10 | 945-2985-ND | RS6-2405S | DC DC CONVERTER 5V 6W | U5 | 10 | 0 | 14.398 | 143.98 |
| 18 | 40 | NUP4114HMR6T1GOSCT-ND  | NUP4114HMR6T1G | TVS DIODE 5.5V 10V 6TSOP | U6, U7, U8, U9 | 40 | 0 | 0.42 | 16.80 |
| 19 | 20 | 296-43594-1-ND | ISO3086TDWR | DGT ISO 2.5KV RS422/RS485 16SOIC | U10, U11 | 20 | 0 | 6.02 | 120.40 |
| 20 | 10 | 497-16632-ND | STM32F765ZGT6 | IC MCU 32BIT 1MB FLASH 144LQFP | U12 | 10 | 0 | 12.081 | 120.81 |
| 21 | 10 | 24LC64T-I/SNCT-ND | 24LC64T-I/SN | IC EEPROM 64K I2C 400KHZ 8SOIC | U14 | 10 | 0 | 0.4 | 4.00 |
| 22 | 10 | MAX7375AXR805+TCT-ND | MAX7375AXR805+T | MEMS OSC XO 8.0000MHZ CMOS SMD | U15 | 10 | 0 | 1.466 | 14.66 |
| 23 | 20 | MC78M15CDTRKGOSCT-ND | MC78M15CDTRKG | IC REG LINEAR 15V 500MA DPAK | U17, U20 | 20 | 0 | 0.367 | 7.34 |
| 24 | 20 | MC79M15CDTRKGOSCT-ND | MC79M15CDTRKG | IC REG LINEAR -15V 500MA DPAK | U18, U19 | 20 | 0 | 0.474 | 9.48 |
| 25 | 10 | MCP1826T-5002E/ETCT-ND | MCP1826T-5002E/ET | IC REG LINEAR 5V 1A 5DDPAK | U21 | 10 | 0 | 1.04 | 10.40 |
| 26 | 10 | MCP1826T-3302E/ETCT-ND | MCP1826T-3302E/ET | IC REG LINEAR 3.3V 1A 5DDPAK | U22 | 10 | 0 | 1.04 | 10.40 |
| 27 | 100 | 490-10748-6-ND | GRM21BR61E106MA73L | CAP CER 10UF 25V X5R 0805 | C22, C23, C24, C25, C26, C48, C50 | 100 | 0 | 0.1818 | 18.18 |
| 28 | 100 | 160-1447-6-ND | LTST-C191KRKT | LED RED CLEAR SMD | LED4, LED5, LED7, LED8, LED9 | 100 | 0 | 0.1609 | 16.09 |
| 29 | 100 | RMCF0603FT470RCT-ND | RMCF0603FT470R | RES 470 OHM 1% 1/10W 0603 | R1, R2, R3, R4, R19, R20 | 100 | 0 | 0.0065 | 0.65 |
| 30 | 100 | 311-120HRCT-ND | RC0603FR-07120RL | RES SMD 120 OHM 1% 1/10W 0603 | R7, R8, R9, R10, R17, R35 | 100 | 0 | 0.0094 | 0.94 |
| 31 | 100 | 311-2.80KHRCT-ND | RC0603FR-072K8L | RES SMD 2.8K OHM 1% 1/10W 0603 | R13, R14, R31, R32 | 100 | 0 | 0.0094 | 0.94 |
| 32 | 100 | RMCF0603FT3K00CT-ND | RMCF0603FT3K00 | RES 3K OHM 1% 1/10W 0603 | R15, R16, R21, R23 | 100 | 0 | 0.0065 | 0.65 |
| 33 | 100 | RMCF0603FT15K4CT-ND | RMCF0603FT15K4 | RES 15.4K OHM 1% 1/10W 0603 | R25, R27, R28, R29 | 100 | 0 | 0.0065 | 0.65 |
| 34 | 100 | RNCP0603FTD10K0CT-ND | RNCP0603FTD10K0 | RES 10K OHM 1% 1/8W 0603 | R33, R40, R41, R44 | 100 | 0 | 0.0273 | 2.73 |
| 35 | 25 | LTC6820IMS#TRPBFCT-ND  | LTC6820IMS#TRPBF | IC INTERFACE SPECIALIZED 16MSOP  | U13, U16 | 25 | 0 | 3.2336 | 80.84 |
| 36 | 100 | 311-1445-1-ND | CC0603KRX5R8BB105 | CAP CER 1UF 25V X5R 0603 | C40, C41, C42, C43, C44, C45, C46, C47, C49, C51 | 100 | 0 | 0.0437 | 4.37 |

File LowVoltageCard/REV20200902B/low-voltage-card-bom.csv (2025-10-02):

Quantity | Designator | Description | Value | Footprint | Supplier Part Number | Manufacturer Part Number | Supplier | Manufacturer
10 | C1, C3, C4, C7, C8, C9, C12, C13, C14, C15 | CAP CER 0.1UF 25V X7R 0603 | 100n | 0603-CAP | 311-1341-1-ND | CC0603KRX7R8BB104 | DigiKey | Yageo Group
5 | C2, C5, C6, C10, C11 | CAP CER 10UF 25V X5R 0603 | 10u | 0603-CAP | 490-12737-1-ND | GRM188R61E106MA73J | DigiKey | Murata
1 | CON1 | TERM BLK 2POS SIDE ENTRY 5MM PCB |  | 1935161 | 277-1667-ND | PT1.5/2-5.0-H | DigiKey | Phoenix Contact
14 | GP1, GP2, GP3, TP1, TP2, TP3, TP4, TP5, TP6, TP7, TP8, TP9, TP10, TP11 | PC TEST POINT NATURAL |  | RCT-0C | A106144CT-ND | 1625854-2 | DigiKey | TE Connectivity
4 | L1, L2, L3, L4 | FERRITE BEAD 30 OHM 0603 1LN | 30R | INDC1608X10N | 732-1591-1-ND | 742792609 | DigiKey | Wurth Electronics
2 | LED1, LED2 | LED GREEN CLEAR 0603 SMD | GREEN | 0603-LED | 732-4980-1-ND | 150060VS75000 | DigiKey | Wurth Electronics
1 | LED3 | LED RED CLEAR 0603 SMD | RED | 0603-LED | 732-4978-1-ND | 150060RS75000 | DigiKey | Wurth Electronics
1 | P1 | TERM BLK 3P SIDE ENT 2.54MM PCB |  | Term Block - 3 pos | A98334-ND | 282834-3 | DigiKey | TE Connectivity
1 | P2 | CONN RCPT 7POS 0.1 GOLD PCB |  | HDR1x7 | A32908-ND | 5-534237-5 | DigiKey | TE Connectivity
1 | P3 | CONN RCPT 3POS 0.1 GOLD PCB |  | HDR1x3 | A32904-ND | 5-534237-1 | DigiKey | TE Connectivity
1 | Q1 | CONN BNC JACK STR 50 OHM PCB |  | 5-1634503-1 | A97581-ND | 5-1634503-1 | DigiKey | AMP - TE CONNECTIVITY
2 | R1, R2 | RES 16 OHM 1% 1/10W 0603 | 16 | 0603-RES | 311-16.0HRCT-ND | RC0603FR-0716RL | DigiKey | Yageo
1 | R3 | RES 100K OHM 1% 1/10W 0603 | 100k | 0603-RES | 311-100KHRCT-ND | RC0603FR-07100KL | DigiKey | YAGEO
2 | R4, R5 | RES 3K OHM 1% 1/10W 0603 | 3k | 0603-RES | 311-3.00KHRCT-ND | RC0603FR-073KL | DigiKey | Yageo
1 | R6 | RES 470 OHM 5% 1/10W 0603 | 470 | 0603-RES | 311-470GRCT-ND | RC0603JR-07470RL | DigiKey | YAGEO
1 | U1 | IC OPAMP DIFF 1 CIRCUIT 8SOIC |  | SOIC127P600X175-8N | 296-46094-1-ND | INA143UA/2K5 | DigiKey | Texas Instruments
1 | U2 | IC ADC 16BIT SAR 10VSSOP |  | TSSOP50P490X110-10N | 296-39883-1-ND | ADS8865IDGSR | DigiKey | Texas Instruments
1 | U3 | TVS DIODE 12V 19V 8SO |  | SOIC127P600X175-8N | 1655-2009-1-ND | SMDA12LCC | DigiKey | SMC Diode Solutions
1 | U4 | Series Voltage Reference IC ±0.2% 25mA SOT-23-3 |  | SOT23-3 | REF3020AIDBZTCT-ND | REF3020AIDBZT | DigiKey | Texas Instruments
1 | U5 | Series Voltage Reference IC ±0.2% 25mA SOT-23-3 |  | SOT23-3 | 296-35920-1-ND | REF3040AIDBZR | DigiKey | Texas Instruments

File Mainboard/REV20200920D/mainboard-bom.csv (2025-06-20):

Quantity | Designator | Description | Value | Footprint | Supplier Part Number | Manufacturer Part Number | Supplier | Manufacturer
7 | -VA1, -VB1, +VA1, +VB1, 3V3, 5V, GND1 | PC TEST POINT NATURAL |  | RCU-0C | A106145CT-ND | 1625854-3 | Digikey | TE Connectivity
6 | C1, C2, C3, C4, C5, C6 | Cap Ceramic 6.8uF 50V JB 10% SMD 1206 85°C Punched Paper T/R | 6.8uF | CAP-1206 | 445-11734-1-ND | C3216JB1H685K160AB | Digikey | TDK
43 | C1SCREW1, C1SCREW2, C1SCREW3, C1SCREW4, C2SCREW1, C2SCREW2, C2SCREW3, C2SCREW4, C3SCREW1, C3SCREW2, C3SCREW3, C3SCREW4, C4SCREW1, C4SCREW2, C4SCREW3, C4SCREW4, C5SCREW1, C5SCREW2, C5SCREW3, C5SCREW4, C6SCREW1, C6SCREW2, C6SCREW3, C6SCREW4, C7SCREW1, C7SCREW2, C7SCREW3, C7SCREW4, C8SCREW1, C8SCREW2, C8SCREW3, C8SCREW4, SCREW1, SCREW2, SCREW3, SCREW4, SCREW5, SCREW6, SCREW7, SCREW8, SCREW9, SCREW10, SCREW11 | MACH SCREW PAN PHILLIPS #4-40 |  |  | KEY1046-ND | 9900 | Digi-Key | Keystone Electronics
16 | C1STANDOFF1, C1STANDOFF2, C2STANDOFF1, C2STANDOFF2, C3STANDOFF1, C3STANDOFF2, C4STANDOFF1, C4STANDOFF2, C5STANDOFF1, C5STANDOFF2, C6STANDOFF1, C6STANDOFF2, C7STANDOFF1, C7STANDOFF2, C8STANDOFF1, C8STANDOFF2 | Hex Standoff Threaded #4-40 Stainless Steel 0.438in (11.11mm) |  |  | 1772-3771-ND | 2056-440-SS-20 | Digikey | RAF
28 | C7, C8, C9, C10, C11, C12, C13, C14, C15, C16, C17, C18, C19, C20, C21, C27, C28, C29, C30, C31, C32, C33, C34, C35, C36, C37, C38, C39 | Capacitor | 0.1uF | 0603-CAP | 311-1343-1-ND | CC0603ZRY5V9BB104 | Digikey | Yageo
7 | C22, C23, C24, C25, C26, C48, C50 | CAP CER 10UF 25V X5R 0805 | 10uF | CAP-0805 | 490-10748-6-ND | GRM21BR61E106MA73L | Digikey | Murata
10 | C40, C41, C42, C43, C44, C45, C46, C47, C49, C51 | CAP CER 1UF 25V X5R 0603 | 1uF | CAP-0603 | 311-1445-6-ND | CC0603KRX5R8BB105 | Digi-Key | Yageo
2 | CON1, CON2 | AMPHENOL ICC (FCI) - ICD15S13E4GV00LF - D-SUB CONN, RCPT, R/A, 15POS, TH |  | ICD15S | 609-5180-ND | ICD15S13E4GV00LF | Digi-Key | Amphenol Communications Solutions
1 | CON3 | TERM BLK 2POS SIDE ENTRY 5MM PCB |  | 1935161 | 277-1667-ND | 1935161 | Digi-Key | Phoenix Contact
1 | CON4 | CONN HEADER SMD 10POS 1.27MM |  | 20021521-00010D4LF | 609-6533-ND | 20021521-00010D4LF | Digikey | Amphenol ICC / FCI
1 | L1 | SMD Common Mode Line Filter WE-SL5 HC, L = 9.00 µH |  | WE-SL5 | 732-2215-6-ND | 744273801 | DigiKey | Wurth Electronics
1 | LED1 | LED BLUE CLEAR 0603 SMD | BLUE | 0603-LED | 160-1647-1-ND | LTST-C191TBKT | DigiKey | Vishay Lite-On
1 | LED2 | LED GREEN CLEAR 0603 R/A SMD | GREEN | 0603-LED | 160-1478-1-ND | LTST-S270KGKT | Digikey | Vishay Lite-On
3 | LED3, LED6, LED10 | LED YELLOW CLEAR SMD | YELLOW | 0603-LED | 160-1448-6-ND | LTST-C191KSKT | Digi-Key | Lite-On Inc.
5 | LED4, LED5, LED7, LED8, LED9 | LED RED CLEAR SMD | RED | 0603-LED | 160-1447-6-ND | LTST-C191KRKT | Digi-Key | Lite-On Inc.
8 | P1, P4, P5, P8, P11, P14, P17, P20 | CONN HEADER VERT 7POS 2.54MM |  | HDR1x7 | 732-5320-ND | 61300711121 | Digi-Key | Wurth Electronics
8 | P2, P3, P6, P7, P12, P13, P18, P19 | CONN HEADER VERT 3POS 2.54MM |  | HDR1x3 - MALE | 732-5316-ND | 61300311121 | Digi-Key | Wurth Electronics
4 | P9, P10, P15, P16 | Board-To-Board Connector, Vertical, Wr-Phd Series, Through Hole, Header, 3, 2.54 Mm |  | HDR1x3 - MALE | 732-5316-ND | 61300311121 | Digikey | Wurth Electronics
6 | R1, R2, R3, R4, R19, R20 | RES 470 OHM 1% 1/10W 0603 | 470 | RES-0603 | RMCF0603FT470RCT-ND | RMCF0603FT470R | Digikey | Stackpole Electronics
2 | R5, R6 | RES SMD 0 OHM JUMPER 1/10W 0603 | 0R, DNP | 0603-RES | P0.0GDKR-ND | ERJ-3GEY0R00V | DigiKey | Panasonic
6 | R7, R8, R9, R10, R17, R35 | RES 120 OHM 1% 1/10W 0603 | 120 | 0603-RES | 311-120HRCT-ND | RC0603FR-07120RL | Digikey | Yageo
2 | R11, R30 | Res Thick Film 0603 1.2K Ohm 1% 0.1W(1/10W) ±100ppm/C Molded SMD Automotive Punched T/R | 1.2k | 0603-RES | P1.20KHCT-ND | ERJ-3EKF1201V | Digikey | Panasonic
9 | R12, R24, R34, R36, R37, R45, R50, R51, R54 | RES SMD 0 OHM JUMPER 1/10W 0603 | 0R | 0603-RES | P0.0GDKR-ND | ERJ-3GEY0R00V | DigiKey | Panasonic
4 | R13, R14, R31, R32 | RES 2.8K OHM 1% 1/10W 0603 | 2.8k | 0603-RES | 311-2.80KHRCT-ND | RC0603FR-072K8L | Digikey | Yageo
4 | R15, R16, R21, R23 | RES 3K OHM 1% 1/10W 0603 | 3k | RES-0603 | RMCF0603FT3K00CT-ND | RMCF0603FT3K00 | DigiKey | Stackpole Electronics
3 | R18, R22, R26 | RES 10K OHM 1% 1/8W 0603 | 10k | RES-0603 | RNCP0603FTD10K0CT-ND | RNCP0603FTD10K0 | DigiKey | Stackpole Electronics
4 | R25, R27, R28, R29 | Res Thick Film 0603 15.4K Ohm 1% 1/10W ±100ppm/C Molded SMD SMD Paper T/R | 15.33k | RES-0603 | RMCF0603FT15K4CT-ND | RMCF0603FT15K4 | Digikey | Stackpole Electronics
4 | R33, R40, R41, R44 | RES 10K OHM 1% 1/8W 0603 | 10k, DNP | RES-0603 | RNCP0603FTD10K0CT-ND | RNCP0603FTD10K0 | DigiKey | Stackpole Electronics
6 | R38, R39, R42, R43, R47, R48 | RES 0 OHM JUMPER 1/4W 1206 | 0 | RES-1206 | 311-0.0ERCT-ND | RC1206JR-070RL | Digikey | Yageo
4 | R46, R49, R52, R53 | RES SMD 0 OHM JUMPER 1/10W 0603 | 0R, DNP | 0603-RES | P0.0GDKR-ND | ERJ-3GEY0R00V | DigiKey | Panasonic
11 | STANDOFF1, STANDOFF2, STANDOFF3, STANDOFF4, STANDOFF5, STANDOFF6, STANDOFF7, STANDOFF8, STANDOFF9, STANDOFF10, STANDOFF11 | HEX STANDOFF #4-40 BRASS 1/2 |  |  | 36-1656-ND | 1656 | Digikey | Keystone Electronics
1 | T1 | XFRMR MAGNETIC 1PORT 1:1 10/100 |  | HX1188NLT | 553-1536-1-ND | HX1188NLT | Digikey | Pulse
29 | TG1, TG2, TG3, TG4, TG5, TG6, TG7, TP1, TP2, TP3, TP4, TP5, TP6, TP7, TP8, TP9, TP10, TP11, TP12, TP13, TP14, TP15, TP16, TP17, TP18, TP19, TP20, TP21, TP22 | Test Point, Yellow, 1-Pin THD, RoHS, Bulk |  | RCU-0C | 62W5138 | 5004 | Newark | Keystone Electronics
4 | U1, U2, U3, U4 | Recom RS6 |  | RS6 DCDC | 945-2987-ND | RS6-2415S | Digikey | Recom
1 | U5 | Recom RS6 |  | RS6 DCDC | 945-2985-ND | RS6-2405S | Digikey | Recom
4 | U6, U7, U8, U9 | TVS DIODE 5.5V 10V 6TSOP |  | TSOP95P280X110-6N | NUP4114HMR6T1GOSCT-ND | NUP4114HMR6T1G | Digikey | ON Semiconductor
2 | U10, U11 | DG ISO 2.5KV RS422/RS485 16SOIC |  | SOIC127P1030X265-16N | 296-43594-1-ND | ISO3086TDWR | Digikey | Texas Instruments
1 | U12 | IC MCU 32BIT 1MB FLASH 144LQFP |  | STM-LQFP144_M | 497-16632-ND | STM32F765ZGT6 | Digikey | STMicroelectronics
2 | U13, U16 | IC INTERFACE SPECIALIZED 16MSOP |  | TSSOP50P490X110-16N | LTC6820IMS#TRPBFCT-ND | LTC6820IMS#TRPBF | Digikey | Analog Devices / Linear Technology
1 | U14 | IC EEPROM 64K I2C 400KHZ 8SOIC |  | SOIC127P600X175-8N | 24LC64T-I/SNCT-ND | 24LC64T-I/SN | Digi-Key | Microchip
1 | U15 | MEMS OSC XO 8.0000MHZ CMOS SMD |  | SOT65P210X110-3N | MAX7375AXR805+TCT-ND | MAX7375AXR805-T | Digikey | Maxim
2 | U17, U20 | IC REG LINEAR 15V 500MA DPAK |  | DPAK229P991X238-3N | MC78M15CDTRKGOSCT-ND | MC78M15CDTRKG | Digikey | ON Semiconductor
2 | U18, U19 | IC REG LINEAR -15V 500MA DPAK |  | DPAK229P991X238-3N | MC79M15CDTRKGOSCT-ND | MC79M15CDTRKG | Digikey | ON Semiconductor
1 | U21 | IC REG LINEAR 5V 1A 5DDPAK |  | 5-DDPAK | MCP1826T-5002E/ETCT-ND | MCP1826T-5002E/ET | Digi-Key | Microchip
1 | U22 | IC REG LINEAR 3.3V 1A 5DDPAK |  | 5-DDPAK | MCP1826T-3302E/ETCT-ND | MCP1826T-3302E/ET | Digikey | Microchip

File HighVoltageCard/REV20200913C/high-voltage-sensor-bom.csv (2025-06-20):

Quantity | Designator | Description | Value | Footprint | Supplier Part Number | Manufacturer Part Number | Supplier | Manufacturer
1 | B1 | CONN BARRIER STRIP 2CIRC 0.325" |  | BARRIER_STRIP | WM13920-ND | 0387007502 | Digi-Key | Molex
1 | BNC1 | CONN BNC JACK STR 50 OHM PCB |  | BNC | A33798-ND | 5227699-1 | Digi-Key | TE Connectivity
5 | C1, C2, C3, C4, C9 | CAP CER 0.1UF 25V Y5V 0603 | 100nF | CAPC1608X87X35NL15T15 | 399-1100-1-ND | C0603C104Z3VACTU | Digi-Key | Kemet
1 | C5 | Chip Capacitor, 1 nF, +/- 5%, 50 V, -55 to 125 degC, 0603 (1608 Metric), RoHS, Tape and Reel | 1nF | CAPC1608X90X35ML10T15 | 490-1451-1-ND | GRM1885C1H102JA01D | Digi-Key | Murata
5 | C6, C7, C8, C10, C11 | CAP CER 10UF 25V X5R 0805 | 10uF | CAP-0805 | 1276-2890-1-ND | CL21A106KAFN3NE | Digi-Key | Samsung
1 | DS1 | LED Green, 75 mW, 80 mA, -55 to 85 degC, 2-Pin SMD, RoHS, Tape and Reel | GREEN | LTST-C193KGKT-5A_V | 160-1828-1-ND | LTST-C193KGKT-5A | Digi-Key | Lite-On
1 | DS2 | LED Uni-Color Blue, 76 mW, 20 mA, -20 to 80 degC, 2-Pin SMD, RoHS, Tape and Reel | BLUE | LTST-C193TBKT_V | 160-1827-1-ND | LTST-C193TBKT-5A | Digi-Key | Lite-On
1 | IC1 | LV 25-P Voltage Sensor |  | LV 25-P | 398-1019-ND | LV 25-P | Digi-Key | LEM USA Inc.
4 | L1, L2, L3, L4 | SMD EMI Suppression Ferrite Bead WE-CBF, Z = 30 Ohm | 40mR | SMD-0603 | 732-1591-1-ND | 742792609 | Digi-Key | Wurth Electronics
1 | P1 | TERM BLK 3P SIDE ENT 2.54MM PCB |  | Term Block - 3 pos | A98334-ND | 282834-3 | Digi-Key | TE Connectivity
1 | P2 | CONN RCPT 7POS 0.1 GOLD PCB |  | HDR1x7 | A32908-ND | 5-534237-5 | Digi-Key | TE Connectivity
1 | P3 | CONN RCPT 3POS 0.1 GOLD PCB |  | HDR1x3 | A106650-ND | 215297-3 | Digi-Key | TE Connectivity
2 | R1, R3 | RES SMD 3K OHM 0.1% 1/10W 0603 | 3k | RESC1608X55X30LL15T15 | P3.0KGCT-ND | ERJ-3GEYJ302V | Digi-Key | Panasonic
1 | R2 | RES 470 OHM 1% 1/10W 0603 | 470 | RESC1608X55X25LL10T15 | 311-470HRCT-ND | RC0603FR-07470RL | Digi-Key | Yageo
1 | R4 | RES SMD 10K OHM 0.1% 1/10W 0603 | 10k | RESC1608X55X30ML20T20 | P10KDBCT-ND | ERA-3AEB103V | Digi-Key | Panasonic
1 | R5 | RES SMD 348 OHM 1% 1W 2512 | 348R | RES-2512 | PT348AFCT-ND | ERJ-1TNF3480U | Digi-Key | Panasonic
1 | R6 | RES SMD 8.45KOHM 0.1% 1/10W 0603 | 8.45k | RESC1608X55X30ML20T20 | P8.45KDBCT-ND | ERA-3AEB8451V | Digi-Key | Panasonic
1 | R8 | RES SMD 4.64KOHM 0.1% 1/10W 0603 | 4.64k | RESC1608X55X30LL20T20 | P4.64KDBCT-ND | ERA-3AEB4641V | Digi-Key | Panasonic
2 | R9, R10 | RES 25K OHM 1% 5W AXIAL | 25k | Axial_5W | WHE25KFETCT-ND | WHE25KFET | Digi-Key | Ohmite
7 | TP1, TP2, TP3, TP4, TP5, TP6, TP7 | Test Point, Yellow, 1-Pin THD, RoHS, Bulk |  | KSTN-5004 | 36-5004-ND | 5004 | Digi-Key | Keystone
1 | U1 | IC ADC 16BIT 1MSPS 10VSSOP |  | VSSOP10 | 296-47183-ND | ADS8860IDGS | Digi-Key | Texas Instruments
1 | U2 | Precision, 20 MHz, 0.9 pA Ib, RRIO, CMOS Operational Amplifier, 1.8 to 5.5 V, -40 to 125 degC, 5-pin SOT23 (DBV5), Green (RoHS & no Sb/Br) |  | DBV0005A_L | 296-29480-1-ND | OPA320AIDBVR | Digi-Key | Texas Instruments
1 | U3 | Low Noise, Very Low Drift, Precision Voltage Reference, -40 to 125 degC, 8-pin VSSOP (DGK), Green (RoHS & no Sb/Br) |  | DGK0008A_N | 296-24507-1-ND | REF5050IDGKT | Digi-Key | Texas Instruments

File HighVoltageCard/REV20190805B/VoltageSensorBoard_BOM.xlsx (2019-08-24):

Quantity | Designator | Manufacturer | Manufacturer Part Number | Supplier 1 | Supplier Part Number 1
4 | *1, IC1, MH1, MH2
1 | B1 | Molex | 0387007502 | Digi-Key | WM13920-ND (https://octopart-clicks.com/click/altium?sku=WM13920-ND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)
1 | BNC1 | TE Connectivity | 5227699-1 | Digi-Key | A33798-ND (https://octopart-clicks.com/click/altium?sku=A33798-ND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)
5 | C1, C2, C3, C4, C9 | Kemet | C0603C104Z3VACTU | Digi-Key | 399-1100-1-ND
1 | C5 | Murata | GRM1885C1H102JA01D | Digi-Key | 490-1451-1-ND
4 | C6, C7, C8, C10 | Samsung | CL21A106KAFN3NE | Digi-Key | 1276-2890-1-ND (https://octopart-clicks.com/click/altium?sku=1276-2890-1-ND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)
1 | DS1 | Lite-On | LTST-C193KGKT-5A | Digi-Key | 160-1828-1-ND
1 | DS2 | Lite-On | LTST-C193TBKT-5A | Digi-Key | 160-1827-1-ND
3 | L1, L2, L3 | Wurth Electronics | 742792609 | Digi-Key | 732-1591-1-ND
2 | P1, P3 | TE Connectivity | 282834-3, 215297-3 | Digi-Key | A106650-ND (https://octopart-clicks.com/click/altium?sku=A106650-ND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)
1 | P2 | TE Connectivity | 215299-6 | Digi-Key | A121761-ND (https://octopart-clicks.com/click/altium?sku=A121761-ND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)
1 | R1 | Panasonic | ERJ3GEYJ302V | Digi-Key | P3.0KGCT-ND
1 | R2 | Yageo | RC0603FR-07470RL | Digi-Key | 311-470HRCT-ND
2 | R3, R7 | Panasonic | ERJ-3GEYJ240V | Digi-Key | P24GCT-ND
1 | R4 | Panasonic | ERA3AEB103V | Digi-Key | P10KDBCT-ND
1 | R5 | TE Connectivity | 3521390RFT | Digi-Key | A116022CT-ND (https://octopart-clicks.com/click/altium?sku=A116022CT-ND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)
1 | R6 | Panasonic | ERA-3AEB8451V | Digi-Key | P8.45KDBCT-ND
1 | R8 | Panasonic | ERA-3AEB4641V | Digi-Key | P4.64KDBCT-ND
2 | R9, R10 | Ohmite | WHE25KFET | Digi-Key | WHE25KFETCT-ND (https://octopart-clicks.com/click/altium?sku=WHE25KFETCT-ND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)
7 | TP1, TP2, TP3, TP4, TP5, TP6, TP7 | Keystone | 5004 | Digi-Key | 36-5004-ND
1 | U1 | Texas Instruments | ADS8860IDGS | Digi-Key | 296-47183-ND (https://octopart-clicks.com/click/altium?sku=296-47183-ND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)
1 | U2 | Texas Instruments | OPA320AIDBVR | Digi-Key | 296-29480-1-ND
1 | U3 | Texas Instruments | REF5050IDGKT | Digi-Key | 296-24507-1-ND

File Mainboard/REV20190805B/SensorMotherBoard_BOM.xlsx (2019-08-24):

Quantity | Designator | Manufacturer | Manufacturer Part Number | Supplier 1 | Supplier Part Number 1
13 | *?, MH1, MH2, MH3, MH4, MH5, MH6, MH7, MH8, MH9, MH10, MH11, MH12
13 | C1, C2, C3, C4, C5, C6, C7, C8, C9, C10, C11, C12, C13 | TDK, Samsung | C3216X5R1H685K160AB, CL21A106KAFN3NE | Digi-Key | 1276-2890-1-ND (https://octopart-clicks.com/click/altium?sku=1276-2890-1-ND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)
1 | CON1 |  |  | Digi-Key | 277-1667-ND (https://octopart-clicks.com/click/altium?sku=277-1667-ND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)
1 | CON2 | Assmann | A-DF15A/KG-T2S | Digi-Key | AE10929-ND (https://octopart-clicks.com/click/altium?sku=AE10929-ND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)
1 | DS1 | Lite-On | LTST-C193KGKT-5A | Digi-Key | 160-1828-1-ND
1 | DS2 | Lite-On | LTST-C193TBKT-5A | Digi-Key | 160-1827-1-ND
1 | L1 | Wurth Electronics | 744273801 | Digi-Key | 732-2215-6-ND
3 | P1, P4, P6 | Wurth Electronics | 61300611121 | Digi-Key | 732-5319-ND (https://octopart-clicks.com/click/altium?sku=732-5319-ND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)
3 | P2, P3, P5 | Wurth Electronics | 61300311121 | Digi-Key | 732-5316-ND (https://octopart-clicks.com/click/altium?sku=732-5316-ND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)
2 | R1, R2 | Panasonic | ERJ3EKF4992V | Digi-Key | P49.9KHCT-ND
1 | R3 | Panasonic | ERJ3GEYJ302V | Digi-Key | P3.0KGCT-ND
1 | R4 | Yageo | RC0603FR-07470RL | Digi-Key | 311-470HRCT-ND
2 | R5, R6 | Panasonic | ERA3AEB154V | Digi-Key | P150KDBCT-ND
1 | R7 | Panasonic | ERJ-3GEY0R00V | Digi-Key | P0.0GCT-ND
9 | TP1, TP3, TP4, TP5, TP6, TP7, TP8, TP9, TP10 | Keystone | 5004 | Digi-Key | 36-5004-ND
2 | U1, U3 | Recom | RS6-2415S | Digi-Key | 945-2987-ND (https://octopart-clicks.com/click/altium?sku=945-2987-ND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)
1 | U2 | Recom | R-78E5.0-1.0 | Digi-Key | 945-2201-ND (https://octopart-clicks.com/click/altium?sku=945-2201-ND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)
1 | U4 | Analog Devices / Linear Technology | LT3045EMSE#TRPBF | Digi-Key | LT3045EMSE#TRPBFCT-ND (https://octopart-clicks.com/click/altium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)
1 | U5 | Analog Devices | LT3094HMSE#PBF | Digi-Key | LT3094HMSE#PBF-ND (https://octopart-clicks.com/click/altium?manufacturer=Analog%20Devices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)

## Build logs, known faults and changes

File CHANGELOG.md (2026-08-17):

# Changelog

This document summarizes the changes introduced to the code base for each release.

## v3.0.2

- Fix daisy chain race condition in data process routing function
- Optimize timing for daisy chain communication

## v3.0.1

- Fix swapped `UART` channels on `FBC` board when daisy chained

## v3.0.0

- Add daisy chain support
- Add daisy chain adapter board
- Update baud rate to 20MHz
- Update `adc_sample` function to be faster
- Rename motherboard folder to mainboard

## v2.0.1

- Fix and standarize PCB release file packages for all boards

## v2.0.0

- Sample and transmit data upon receipt of `SYNC_ADC` interrupt
- Remove `SYNC_TX` interrupt

## v1.0.0

Initial commit of released code base.

- Communication interface for AMDC v1.0.x - v1.2.x

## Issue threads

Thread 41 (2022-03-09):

Update analog front end on current sensor card

npetersen2, 2022-03-09:
After many months of using the current sensor cards, I have found that the analog conditioning front-end drifts slightly over time...

Recall how the circuitry works:
1. the LEM sensor outputs a current proportional to the sense current
2. a burden resistor converts this current to a voltage
3. the voltage is conditioned and sensed by ADC
4. the digital ADC code is sent to the AMDC

The issue is that the 0A input voltage into the ADC is a mid-scale value... i.e. VREF/2 or something. This means that the final ADC code the user gets on the AMDC is not zero for 0A current. It is some value based on the circuitry. The issue is that this mid-scale value slowly drifts over period of months such that the offset is not fixed... This caused ~100mA of offset for me, which was problematic.

Note that the GAIN of the sensor and analog circuitry is pretty stable... I found no issues with the gain. Only the offset.

My quick fix is to simply calibrate the offset at boot every time I run the bench... I flow 0A of current and record the mid-scale voltage and just subtract that from the ADC.

## TODO

A better solution would be to move to an analog front that does this offset calibration in hardware... see the LV sensor card for an example of how to do this.

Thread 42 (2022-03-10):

Cost optimize voltage sense board

npetersen2, 2022-03-10:
The present design of the voltage sensor board is built around the `Voltage Transducer LV 25-P` from LEM.

This requires a (large) burden resistor across the HV input. The current through the burden resistor flows through the LEM device, is isolated, and a proportional current output is produced. Then, this goes across a load resistor where the voltage produced is measured.

**The LEM device costs $60-$68 in low quantities from Digi-Key...** see: https://www.digikey.com/en/products/detail/lem-usa-inc/LV-25-P/409832

For our applications, we do not need this LEM device... there are much cheaper, smaller devices we could use to measure high voltages. We simply need a voltage divider resistance network! However, the isolation is the harder part.

## Potential Ideas

An obvious idea is to simply use a small SMD resistor network to divide the input voltage to a low range: 0V to 2V. Then, use an isolated amplifier with unity gain to feed the existing ADC on the board. E.g. the `TI AMC1311` part would be perfect for this: https://www.ti.com/lit/ds/symlink/amc1311.pdf -- in fact, it is designed specifically for this. And it costs <$10 in low quantity on Digi-Key... The only thing we would require is a small isolated power supply to drive the HV side of the AMC1311, which is not too hard.

There are many other options and devices which are designed for HV sensing which are much cheaper than the LEM device.

TI sells integrated isolated delta-sigma ADCs which can directly sense and digitize the voltage divider output... However, this is not compatible with the SAR ADC architecture on the AMDS.

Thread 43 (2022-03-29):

Fix Current Card BOM

aimthiazz, 2022-03-29:
The Current Card BOM has 4 current sensors instead of 1 (See attached image). This needs to be fixed.

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

npetersen2, 2022-03-30:
Thanks @aimthiazz

This is caused by the following:
1. the `Supplier Part Number 1` field in Altium is blank for a component
2. the BOM is exported with "group by `Supplier Part Number 1`" selected

This means that, in Altium, the LEM sensor is indeed NOT specified 4 times, but instead, that the LEM sensor has no P/N specified.

## TODO

The real TODO here is:
1. Update the LEM sensor P/N to be valid
2. Mark the `TitleBlockWEMPEC` schematic symbol to NOT be included in the autogenerated BOM (i.e. "Graphical" component)
3. Mark the `M3` schematic symbol to be "Mechanical" only, i.e. still goes to the PCB layout, but not included in the BOM. This is correct since the `M3` refers to the `MH1` and `MH2` which are mounting holes. These should not be in the BOM!

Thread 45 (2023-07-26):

Add information on how to use LA100-P to current sense board documentation

elsevers, 2023-07-26:
The current sense board documentation describes how to use the LA50-P current transformer, but increasingly, we are also using the LA100-P current transformer to reach higher currents. Let’s update the documentation to describe how to use the LA100-P. This will involve editing the [docs readme](https://github.com/Severson-Group/AMDS/blob/develop/CurrentCard/docs/README.md) `Burden Resistor` and `Current Sensors Gains` subsections.

While the LA55-P talks about a sensing range of +-70A. Let’s write the documentation for 150A for the LA100-P.

Please also add the LA100-P to the BOM CSV file.

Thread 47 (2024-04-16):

Update AMDS Interface to AMDC

codecubepi, 2024-04-16:
- [x] Create "`amds`" development branch off of `v1.3-staging` in AMDC-Firmware
- [x] Create branch off of `develop` in AMDS repo
- [x] Get working AMDC+AMDS setup and probe the interface between the boards to understand the timing
- [x] Update AMDS's firmware to send data back to AMDC's new IP driver over UART immediately after SPI communications from daughtercards are complete

Also see https://github.com/Severson-Group/AMDC-Firmware/issues/365

npetersen2, 2024-05-14:
@codecubepi will make a new issue which documents the testing which needs to be completed before merging the PR linked to this.

codecubepi, 2024-05-22:
See [#388](https://github.com/Severson-Group/AMDC-Firmware/issues/388) and [#389](https://github.com/Severson-Group/AMDC-Firmware/issues/389) in the AMDC-Firmware repo.

Closed 2024-06-20.

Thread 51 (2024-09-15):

Formalize AMDS release approach and revise history

elsevers, 2024-09-15:
@codecubepi , @npetersen2 -- collecting a plan on how to handle AMDS releases:

# Versioning Approach
Per [this comment](https://github.com/Severson-Group/AMDS/pull/48#issuecomment-2351297892) lets plan to
- have the AMDS be on its own release numbering system which follows the [same approach as the AMDC](https://docs.amdc.dev/firmware/development/index.html#releases) --> i.e. `vA.B.C`, changelog, and use of tags/releases
- we'll add to the AMDC docs a requirements section that indicates which version of the AMDS every release of the AMDC requires; we anticipate placing this near the top of [AMDS Interface doc](https://docs.amdc.dev/getting-started/user-guide/amds-interface/)
- further out in the future, we may set the AMDC up to query the AMDS at boot-up to determine the firmware version compatibility

# Revise history

Looking through the AMDS commit history I suggest the following:
1. We create a `V1.0.0` release by branching off of 3e2b936 with a commit that adds a `changelog`. We create a `V1.0.x` branch pointing to this commit.
2. We merge the `v1.0.x` branch into `develop` (which has the new code necessary for the timing manager since #48 was merged)
3. We proceed with a `v2.0.0` release: create a new commit on `develop` that adds a changelog entry, create a `v2.0.x` branch here. (note that this is indeed a major release (`v2.0.0`) because the PR #48 adds a feature that changes the interface to the AMDC)
4. We delete the `v1.3.x` tag / release (because now we have the `v2.0.0` release)
5. We create a new section near the top of [AMDS Interface doc](https://docs.amdc.dev/getting-started/user-guide/amds-interface/) of what version of AMDS is required for each release of AMDC. I think it will be a table with row 1 showing `AMDC v1.0.x - v1.2.x   |  AMDS >= 1.0`; `AMDC 1.3.x  |  AMDS >= 2.0`

(We'll set up default branches and branch protection rules in AMDS just like AMDC to point to `v1.1.x` etc)

elsevers, 2024-09-15:
@codecubepi , @npetersen2 -- one question: with the latest upgrades for the timing manager (#48), is the current AMDS code still compatible with AMDC v1.2 and lower?

codecubepi, 2024-09-15:
> codecubepi , npetersen2 -- one question: with the latest upgrades for the timing manager (#48), is the current AMDS code still compatible with AMDC v1.2 and lower?

Umm... maybe? The old AMDC Firmware (pre-v1.3) sends two interrupts to the AMDS: one tells it to sample its sensors (SYNC_ADC), the second tells it to return the latest data (SYNC_TX). With the Timing Manager introduced in v1.3, the idea is that a sensor interface receives one signal from the TM telling it to sample data, and once data is sampled, it is assumed that it should be returned immediately. It's a different philosophy of data collection. Therefore in the new AMDS code, the SYNC_TX interrupt has been removed, as the AMDS will both collect _and return data_ with each SYNC_ADC interrupt.

In the old AMDC-Firmware, SYNC_ADC is already aligned with the PWM carrier. With the new AMDS code sending back the data automatically with each occurence of the SYNC_ADC signal, you would have to make sure the v1.2 AMDC driver is _expecting_ the data. So it _may be_ possible if a user can guarantee that their control code is calling `motherboard_request_new_data()` in sync with the PWM carrier and SYNC_ADC signal. But without the Timing Manager to synchronize the control code to the PWM carrier (and by extension the SYNC_ADC signal), I'm not sure how this guarantee could be made. Note that this hasn't been tested, it's just my speculating.

elsevers, 2024-09-15:
Thanks @codecubepi. So this brings up a question:

in the AMDC, `vA.B.C`:
- incrementing `B` for a new release signifies a minor release, which is the addition of a new feature and is supposed to be safe for everyone to upgrade to;
- incrementing `A` signifies a major release, which likely breaks / changes old functionality and upgrading to this requires changes to user code.

If we employ the same logic to the AMDC, is this newest release actually `v2.0.0` because it potentially breaks user code that is running on the AMDC?

Maybe the counter argument is that if a user upgrades both the AMDC and the AMDS at the same time, their user code stays the same and doesn't need changing?

npetersen2, 2024-09-15:
I agree, is is a bit hairy to say the `v1.3.0` release is really a "minor release" but I argue it actually is:

Apart from some function renaming (which yes, theoretically pushes it to a major release, but in practice, is just fixing silly names from years past), the `v1.3.0` is indeed backwards-compatible for users. Users can download the new code, and their existing user code should work as before.

The difference here is that, the *AMDS* changed, which is a separate system....so, really, this new AMDS code should be `v2` and the old AMDS code should be `v1`. And, in the AMDC firmware, the new `v1.3.0` simply requires `>= v2` while the previous AMDC firmware (i.e., `v1.2.0` and before) require `< v2` for the AMDS

elsevers, 2024-09-16:
Thanks! I screwed up my *AMDC* and *AMDS* labels in my question, but you answered what I was really wondering anyway:

This new release of the *AMDS* should be `v2.0.0`. I'll update the issue description accordingly.

Closed 2024-11-10.

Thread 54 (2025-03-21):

Update mainboard ordering documentation

Known4225, 2025-03-21:
[Mainboard ordering documentation](https://github.com/Severson-Group/AMDS/tree/v2.0.x/Mainboard/REV20200920D) is written for a quantity of 10 boards.

## Context

[Here](https://github.com/Severson-Group/AMDC-Hardware/tree/develop/REV20231005F) is the documentation listed on the AMDC repo, there is also a docs page for [obtaining hardware](https://docs.amdc.dev/hardware/obtaining-hardware.html) for the AMDC

## Approach

Close this issue via PR that does the following:
- Update quantity to 1
- Review the two tables and add appropriate titles for each table
- Include list of vendors that have been successfully ordered from
- Use `mainboard` and `sensor cards` instead of `motherboard` and `daughtercards`

mohamed-dek1, 2025-03-28:
@elsevers, can you review this PR?

##

- #55

Known4225, 2025-04-07:
Per 04/07:

Mohamed will be splitting the PR in 2. One for the bom, as to not delay the order of the AMDS boards, and one for updating the docs.

mohamed-dek1, 2025-04-09:
Following PR has been made to merge the changes made to the BOM

- #56

mohamed-dek1, 2025-04-14:
I think the BOM needs to be reviewed because the quantity for each part doesn't seem to match the number of references. It looks like when the BOM was originally made, it was written to order every component through DigiKey, which meant the quantities were rounded to each component's respective bulk amount.

mohamed-dek1, 2025-04-14:
As of 04/14, both PRs have been merged.

Closed 2025-04-14.

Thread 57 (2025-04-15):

Rename files in REV20200920D to follow dash-case naming convention

elsevers, 2025-04-15:
# Abstract
Rename files in [REV20200920D](https://github.com/Severson-Group/AMDS/tree/v2.0.x/Mainboard/REV20200920D) to follow dash-case naming convention

# Context
We have agreed to use the [`dash-case` naming convention](https://github.com/Severson-Group/KnowledgeBase/blob/main/CONTRIBUTING.md#file-naming) for documentation files.

# Approach

Close this issue with a PR that
- updates the files in the [REV20200920D](https://github.com/Severson-Group/AMDS/tree/v2.0.x/Mainboard/REV20200920D) to use the [`dash-case` naming convention](https://github.com/Severson-Group/KnowledgeBase/blob/main/CONTRIBUTING.md#file-naming).
- renames [Pick_Place_for_SensorMotherBoard.csv](https://github.com/Severson-Group/AMDS/blob/v2.0.x/Mainboard/REV20200920D/Pick_Place_for_SensorMotherBoard.csv) to eliminate the reference to mother board (use main board instead)

mohamed-dek1, 2025-04-17:
This issue is being closed per PR:

- #58

Closed 2025-04-17.

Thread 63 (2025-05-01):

Update BOM and pick-place file for AMDC mainboard

elsevers, 2025-05-01:
# Abstract

# Context

This issue is collecting items that came up during ordering AMDS boards as part of this issue:
- https://github.com/Severson-Group/Lab/issues/279

## Item 1:

R5, R6 on BOM: "Value" was listed as DNP, ~it is supposed to be 0~ CORRECTION: They should indeed be DNP to avoid ground loops as explained [here](https://github.com/Severson-Group/AMDS/pull/62#issuecomment-2858237796).

## Item 2:

R41, R33, R52, R46, R40, R44, R49, R53 in pick-and-place listed as DNP, it is supposed to be Resistor.

UPDATE: R45, R50, R51, R54 should be populated with 0 Ohm resistors, as indicated in the schematic. We have confirmed that R41, R33, R52, R46, R40, R44, R49, R53 should not be populated. See notes [here](https://github.com/Severson-Group/AMDS/pull/62#issuecomment-2847896763).

## Item 3:

There are encoding issues in the pick and place file and question marks that are causing confusion with Screaming Circuits.

# Approach

Close this issue via a PR that resolves these issues

Closed 2025-05-07.

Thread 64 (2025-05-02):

Add ODB++ files to AMDS release rev D folder

elsevers, 2025-05-02:
# Abstract

Add ODB++ files to AMDS release [rev D folder](https://github.com/Severson-Group/AMDS/tree/v2.0.x/Mainboard/REV20200920D)

# Context

Related issue:
- https://github.com/Severson-Group/Lab/issues/279

We are currently in the process of purchasing assembled AMDS boards and are finding that the assembly shops prefer for us to provide ODB++ files. We are currently including these files in the AMDC release [see here](https://github.com/Severson-Group/AMDC-Hardware/tree/develop/REV20231005F/odb) and would like to also include them in the [AMDS release folder](https://github.com/Severson-Group/AMDS/tree/v2.0.x/Mainboard/REV20200920D) so that users do not need to open up Altium in order to purchase assembled boards.

# Approach

Close this issue via a PR that adds the ODB files

Closed 2025-05-08.

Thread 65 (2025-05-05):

Add PCB layers PDF to the AMDS mainboard release rev D folder

elsevers, 2025-05-05:
# Abstract

Add PCB layers PDF to AMDS release [rev D folder](https://github.com/Severson-Group/AMDS/tree/develop/Mainboard/REV20200920D)

# Context

Related issue:
- https://github.com/Severson-Group/Lab/issues/279
- #64

We are currently in the process of purchasing assembled AMDS boards and this is causing us to go back through our various release folders on board designs. It is helpful to have a PDF of the PCB layer stack up so that users do not have to open up Altium in order to understand the details on how the board is routed. As an example, in the AMDC repo, we do this with [pcb-layers.pdf](https://github.com/Severson-Group/AMDC-Hardware/blob/develop/REV20231005F/pcb-layers.pdf).

# Approach

Close this issue via a PR that adds a `pcb-layers.pdf` file to the repo. Use the AMDC's [pcb-layers.pdf](https://github.com/Severson-Group/AMDC-Hardware/blob/develop/REV20231005F/pcb-layers.pdf) as an example.

Closed 2025-05-08.

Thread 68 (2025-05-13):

Add mechanical components to schematic and BOM

elsevers, 2025-05-13:
# Abstract
Add mechanical components to schematic and BOM for [Rev D release](https://github.com/Severson-Group/AMDS/tree/v2.0.x/Mainboard/REV20200920D)

# Context
We are in the process of updating our release folders for our various designs. Related issues for AMDS:
- #63
- #64
- #65

@mohamed-dek1 has been working on adding mechanical components to schematics in Altium so that they auto populate on the BOM. For example:
- https://github.com/Severson-Group/AMDC-Hardware/pull/261
- https://github.com/Severson-Group/AMDC-Hardware/pull/259

We discovered that the current AMDS release files on the `develop` branch do not show the mechanical components on the schematic and BOM.

# Approach

Close this issue via a PR that adds the mechanical components to the [rev D](https://github.com/Severson-Group/AMDS/tree/v2.0.x/Mainboard/REV20200920D) schematic and BOM.

mohamed-dek1, 2025-05-16:
per 05/16:

The mechanical components used to hold up the board also need to be added to the schematic and BOM.

elsevers, 2025-05-17:
## Update on Standoffs

1. The AMDS needs two different stand-off solutions. One for the main board to be lifted off of the table and one for the sensorcards.
2. The AMDS mainboard's currently released [BOM](https://github.com/Severson-Group/AMDS/blob/v2.0.x/Mainboard/REV20200920D/SensorMotherBoard_BOM_10qty.csv) lists only one stand-off:
    - [732-10550-ND](https://www.digikey.com/en/products/detail/w%C3%BCrth-elektronik/970110321/6174770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): 11mm M3 stand off (and associated M3 screws `36-7689-1-ND`). I think this is for holding the mainboard off the table, NOT for the sensor cards
    - The AMDC BOM uses 4-40 , 1/2" standoffs. **Let's switch the standoffs (and screws) to hold the mainboard off of the table to match [the  AMDC](https://github.com/Severson-Group/AMDC-Hardware/blob/develop/REV20231005F/bom-rev-f.csv)** so we have fewer parts to stock.
        - After making the switch, we'll need to update the [Google ME 76 Hardware Sheet](https://docs.google.com/spreadsheets/d/16eWoWGY_jfMSNuZQeauz20iACJenNDp30TCMVM3sQI8/edit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)
2. So what are the correct stand-offs for the sensor cards?
    - The [current](https://github.com/Severson-Group/AMDS/blob/v2.0.x/CurrentCard/REV20200830C/CurrentSensorBoard_BOM.csv) and [high voltage](https://github.com/Severson-Group/AMDS/blob/v2.0.x/HighVoltageCard/REV20200913C/VoltageCard_bom_qty_10.xlsx) cards do not indicate any standoffs in their BOMs.
    - The [low voltage card](https://github.com/Severson-Group/AMDS/blob/v2.0.x/LowVoltageCard/REV20200902B/BOM_qty1.csv) is quite confusing. The [BOM](https://github.com/Severson-Group/AMDS/blob/v2.0.x/LowVoltageCard/REV20200902B/BOM_qty1.csv)...
        - description refers to a 4-40 standoff / screw (great! this matches the AMDC!)
        - but... the standoff part number provided ([732-10538-ND](https://www.digikey.com/en/products/detail/w%C3%BCrth-elektronik/970090321/6174758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)) points to an M3 9mm standoff. Oy..........
    - @noguchi-takahiro and I tried to use one of the AMDC 4-40 1/2" stand-offs for these boards but discovered that this is too long, the sensor card will not seat properly on the AMDS
    - Recently, we have converged on using a 4-40 3/8" stand-off for the Kaman I/O board. See this:
        - https://github.com/Severson-Group/Lab/issues/309#issuecomment-2831355635
        - It would be wonderful if we could re-use these stand-offs for the sensor cards too. This would reduce the number of unique parts we must stock.

## Next steps

@mohamed-dek1, please:
1. Figure out the correct stand-offs for the sensor cards. Try using the [4-40 3/8" stand-off parts we are now using for the Kaman I/O board](https://github.com/Severson-Group/Lab/issues/309#issuecomment-2831355635) to connect a sensor card to the AMDS. Does this seem like a reasonable solution? How does the height compare to the current stand-offs that are used? Take a picture / show me it.
2. Figure out our strategy for what stand-offs go on what BOM. For sure the main-board standoffs (to lift it off the table) go on the main board's BOM and schematic. But where should the sensor card standoffs go? They could reasonably go on either the main board's material or the sensor cards. However, putting them on the sensor card's is duplicative, since we have three sensor card designs. **Therefore, please indicate all stand-offs** (those to lift the main board off the table and those in between the sensor cards and the main board) **on the main board schematic + BOM.**
3. Create your PR to close this issue.

mohamed-dek1, 2025-05-19:
## 4-40 3/8" Stand-Off (proposed)

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

## M3 11mm Stand-Off with M3 6mm Screw (current)

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

##
There's a gap between the board and standoff when using the 4-40 3/8" stand-offs, however, when using the M3 11mm stand-offs, the jumper with fewer pins doesn't reach the ground fully. I spoke with @noguchi-takahiro and think that we should continue using our existing stand-off solution for mounting the sensor boards.

##
I agree that all standoffs and screws should be on the mainboard schematic + BOM. One thing I noticed was that there is another component that holds the sensor cards to the mainboard.

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

I think we should use 2 screws on either end of the stand-off such that they are short enough as to not hit each other and still fasten the sensor card and mainboard to each other.

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

mohamed-dek1, 2025-05-20:
per 05/20:

@knvprasad-dr and I have looked into the mounting setup for the sensor boards and think that using one 11mm M3 standoff and 2 6mm M3 screws are sufficient in mounting the sensor cards to the mainboard. Due to the thickness of both PCBs, we are able to get away with using 2 6mm rather than shorter ones.

11mm standoff + 2 * (1.6mm thickness boards) = 14.2mm

14.2mm - 2 * (6mm screw) = 2.2mm of clearance between screws within the standoff.

elsevers, 2025-05-22:
Thanks @mohamed-dek1. Good work here and I think we'll need to chat to finalize details on this.

One request in the meantime: can you identify an option for these standoffs in imperial sizing that use a 4-40 thread? I.e., maybe 7/16" length? Since we are using imperial stand-offs for the AMDC, I am thinking we should discuss what it would mean to standardize on that across all stand-offs so that we have fewer parts to stock

(CC @knvprasad-dr regarding the full-bridge converter)

mohamed-dek1, 2025-05-23:
per 05/23:

add [1772-3771-ND](https://www.digikey.com/en/products/detail/raf-electronic-hardware/2056-440-SS-20/9836151) to the [ME 76 Hardware Sheet](https://docs.google.com/spreadsheets/d/16eWoWGY_jfMSNuZQeauz20iACJenNDp30TCMVM3sQI8/edit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)

mohamed-dek1, 2025-06-09:
@elsevers, what chart string should I use to order the standoffs?

mohamed-dek1, 2025-06-09:
Standoffs are being ordered in the following issue:

- https://github.com/Severson-Group/Lab/issues/341

Closed 2025-06-23.

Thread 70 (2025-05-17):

Clean up the AMDS Current Card release files to match the template of the AMDS mainboard and AMDC

elsevers, 2025-05-17:
# Abstract

Update current sensor card [REV20200830C](https://github.com/Severson-Group/AMDS/tree/v2.0.x/CurrentCard/REV20200830C) release files to match template of the [AMDC](https://github.com/Severson-Group/AMDC-Hardware/tree/develop/REV20231005F) and [AMDS mainboard](https://github.com/Severson-Group/AMDS/tree/develop/Mainboard/REV20200920D)

# Context

We have recently conducted a review of the [AMDC](https://github.com/Severson-Group/AMDC-Hardware/tree/develop/REV20231005F) and [AMDS](https://github.com/Severson-Group/AMDS/tree/develop/Mainboard/REV20200920D) release files (naming convention, BOM contents, and `README.md` files). See these issues:
- https://github.com/Severson-Group/AMDC-Hardware/issues/254
- https://github.com/Severson-Group/AMDC-Hardware/issues/256
- [#256 ](https://github.com/Severson-Group/AMDS/issues/54)

We are also currently re-thinking our mechanical components for the AMDS:
- https://github.com/Severson-Group/AMDS/issues/68

We have decided that the sensor cards should not list mechanical components (see [here](https://github.com/Severson-Group/AMDS/issues/68#issuecomment-2888600284))

# Approach

Close this issue via a PR and updates the sensor card release folder so that:
1. We have all of the expected files in the release folder listed [here](https://github.com/Severson-Group/KnowledgeBase/blob/main/PCB-Design-Guidelines.md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)
2. All files are named according to the [dash-case naming convention](https://github.com/Severson-Group/KnowledgeBase/blob/main/CONTRIBUTING.md#file-naming)
3. The main README.md has the standard template material as we agreed upon for the AMDC and AMDS (please inspect that material that is in this readme and update accordingly)
4. Clean up / revise the BOM to be more professional and match the changes we are making to the [AMDC](https://github.com/Severson-Group/AMDC-Hardware/tree/develop/REV20231005F) and [AMDS](https://github.com/Severson-Group/AMDS/tree/develop/Mainboard/REV20200920D)
5. Remove any listing of screws or stand-offs from the BOM

mohamed-dek1, 2025-05-26:
@elsevers, this is ready for review.

Closed 2025-06-16.

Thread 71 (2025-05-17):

Clean up the AMDS Low Voltage Card release files to match the template of the AMDS mainboard and AMDC

elsevers, 2025-05-17:
# Abstract

Update low voltage sensor card [REV20200902B](https://github.com/Severson-Group/AMDS/tree/v2.0.x/LowVoltageCard/REV20200902B) release files to match template of the [AMDC](https://github.com/Severson-Group/AMDC-Hardware/tree/develop/REV20231005F) and [AMDS mainboard](https://github.com/Severson-Group/AMDS/tree/develop/Mainboard/REV20200920D)

# Context

We have recently conducted a review of the [AMDC](https://github.com/Severson-Group/AMDC-Hardware/tree/develop/REV20231005F) and [AMDS](https://github.com/Severson-Group/AMDS/tree/develop/Mainboard/REV20200920D) release files (naming convention, BOM contents, and `README.md` files). See these issues:
- https://github.com/Severson-Group/AMDC-Hardware/issues/254
- https://github.com/Severson-Group/AMDC-Hardware/issues/256
- [#256 ](https://github.com/Severson-Group/AMDS/issues/54)

We are also currently re-thinking our mechanical components for the AMDS:
- https://github.com/Severson-Group/AMDS/issues/68

We have decided that the sensor cards should not list mechanical components (see [here](https://github.com/Severson-Group/AMDS/issues/68#issuecomment-2888600284))

# Approach

Close this issue via a PR and updates the sensor card release folder so that:
1. We have all of the expected files in the release folder listed [here](https://github.com/Severson-Group/KnowledgeBase/blob/main/PCB-Design-Guidelines.md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)
2. All files are named according to the [dash-case naming convention](https://github.com/Severson-Group/KnowledgeBase/blob/main/CONTRIBUTING.md#file-naming)
3. The main README.md has the standard template material as we agreed upon for the AMDC and AMDS (please inspect that material that is in this readme and update accordingly)
4. Clean up / revise the BOM to be more professional and match the changes we are making to the [AMDC](https://github.com/Severson-Group/AMDC-Hardware/tree/develop/REV20231005F) and [AMDS](https://github.com/Severson-Group/AMDS/tree/develop/Mainboard/REV20200920D)
5. Remove any listing of screws or stand-offs from the BOM

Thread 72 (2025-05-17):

Clean up the AMDS High Voltage Card release files to match the template of the AMDS mainboard and AMDC

elsevers, 2025-05-17:
# Abstract

Update high voltage sensor card [REV20200913C](https://github.com/Severson-Group/AMDS/tree/v2.0.x/HighVoltageCard/REV20200913C) release files to match template of the [AMDC](https://github.com/Severson-Group/AMDC-Hardware/tree/develop/REV20231005F) and [AMDS mainboard](https://github.com/Severson-Group/AMDS/tree/develop/Mainboard/REV20200920D)

# Context

We have recently conducted a review of the [AMDC](https://github.com/Severson-Group/AMDC-Hardware/tree/develop/REV20231005F) and [AMDS](https://github.com/Severson-Group/AMDS/tree/develop/Mainboard/REV20200920D) release files (naming convention, BOM contents, and `README.md` files). See these issues:
- https://github.com/Severson-Group/AMDC-Hardware/issues/254
- https://github.com/Severson-Group/AMDC-Hardware/issues/256
- [#256 ](https://github.com/Severson-Group/AMDS/issues/54)

We are also currently re-thinking our mechanical components for the AMDS:
- https://github.com/Severson-Group/AMDS/issues/68

We have decided that the sensor cards should not list mechanical components (see [here](https://github.com/Severson-Group/AMDS/issues/68#issuecomment-2888600284))

# Approach

Close this issue via a PR and updates the sensor card release folder so that:
1. We have all of the expected files in the release folder listed [here](https://github.com/Severson-Group/KnowledgeBase/blob/main/PCB-Design-Guidelines.md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)
2. All files are named according to the [dash-case naming convention](https://github.com/Severson-Group/KnowledgeBase/blob/main/CONTRIBUTING.md#file-naming)
3. The main README.md has the standard template material as we agreed upon for the AMDC and AMDS (please inspect that material that is in this readme and update accordingly)
4. Clean up / revise the BOM to be more professional and match the changes we are making to the [AMDC](https://github.com/Severson-Group/AMDC-Hardware/tree/develop/REV20231005F) and [AMDS](https://github.com/Severson-Group/AMDS/tree/develop/Mainboard/REV20200920D)
5. Remove any listing of screws or stand-offs from the BOM

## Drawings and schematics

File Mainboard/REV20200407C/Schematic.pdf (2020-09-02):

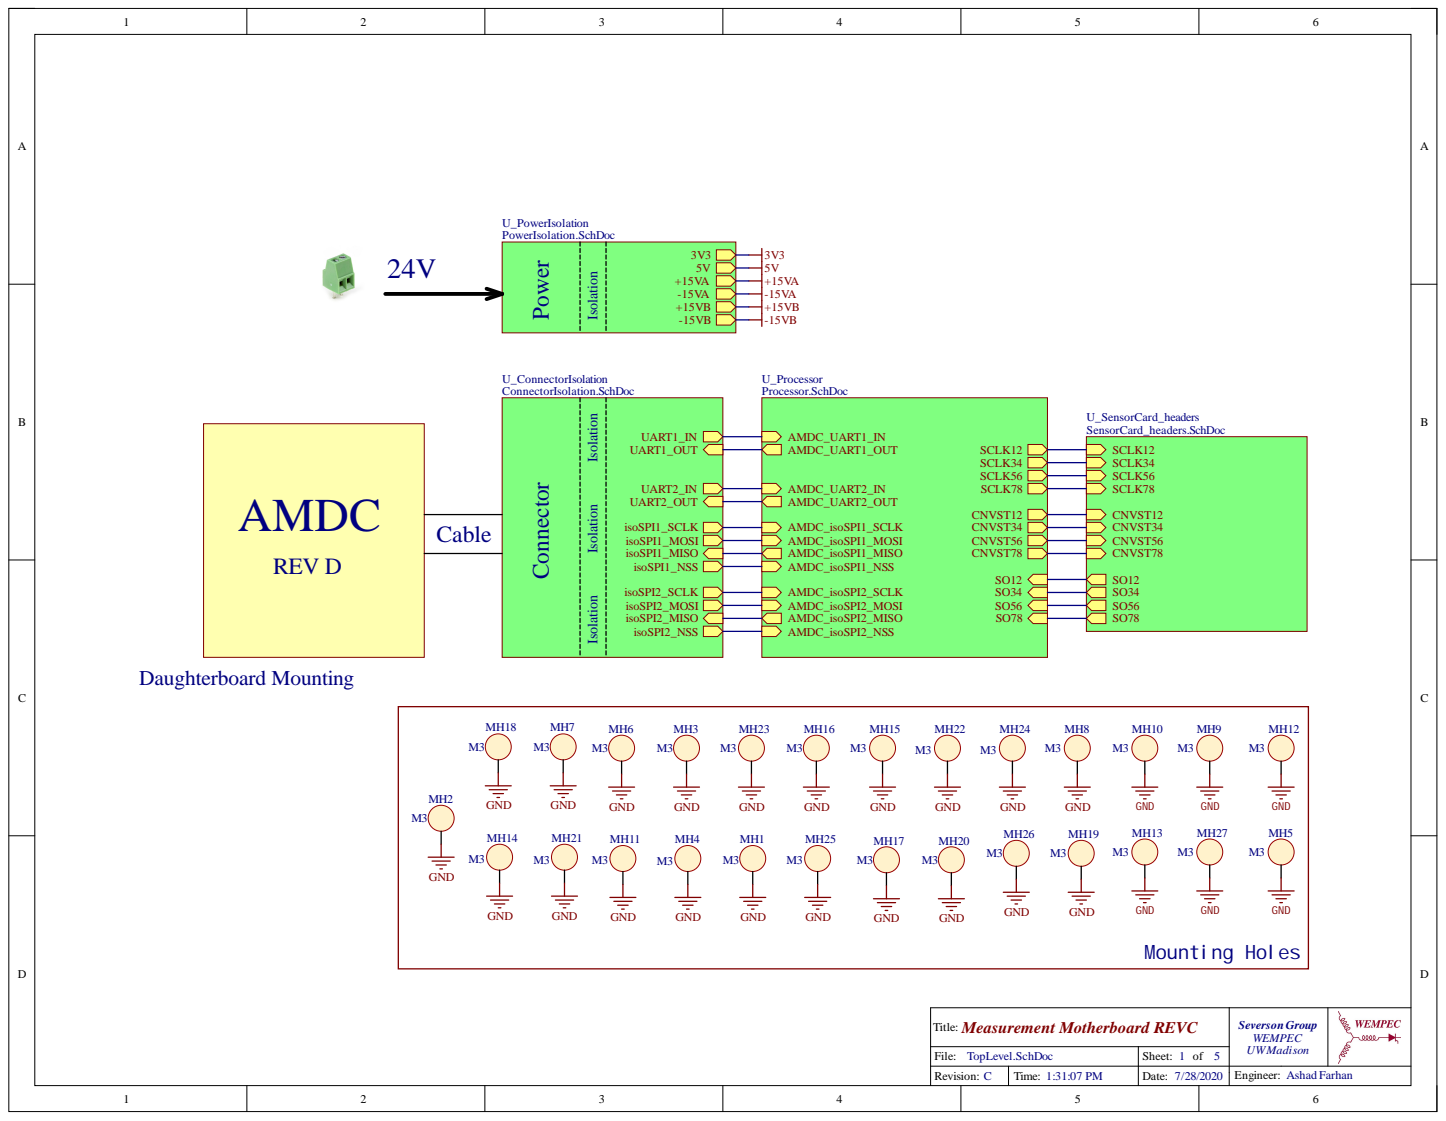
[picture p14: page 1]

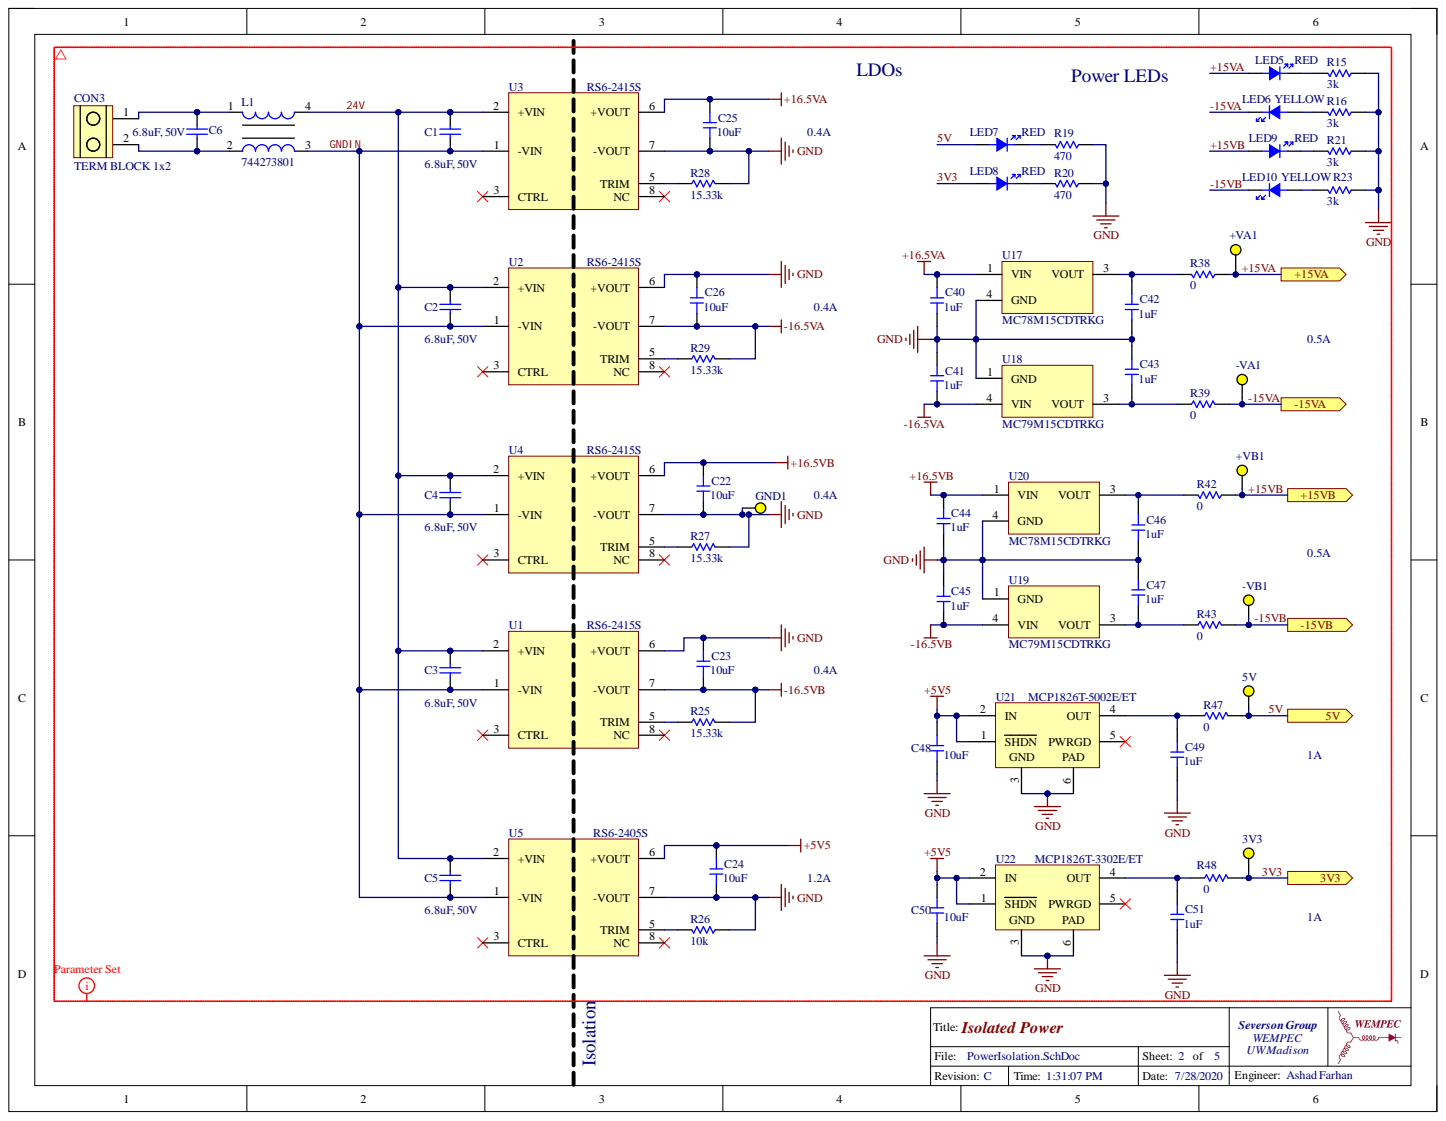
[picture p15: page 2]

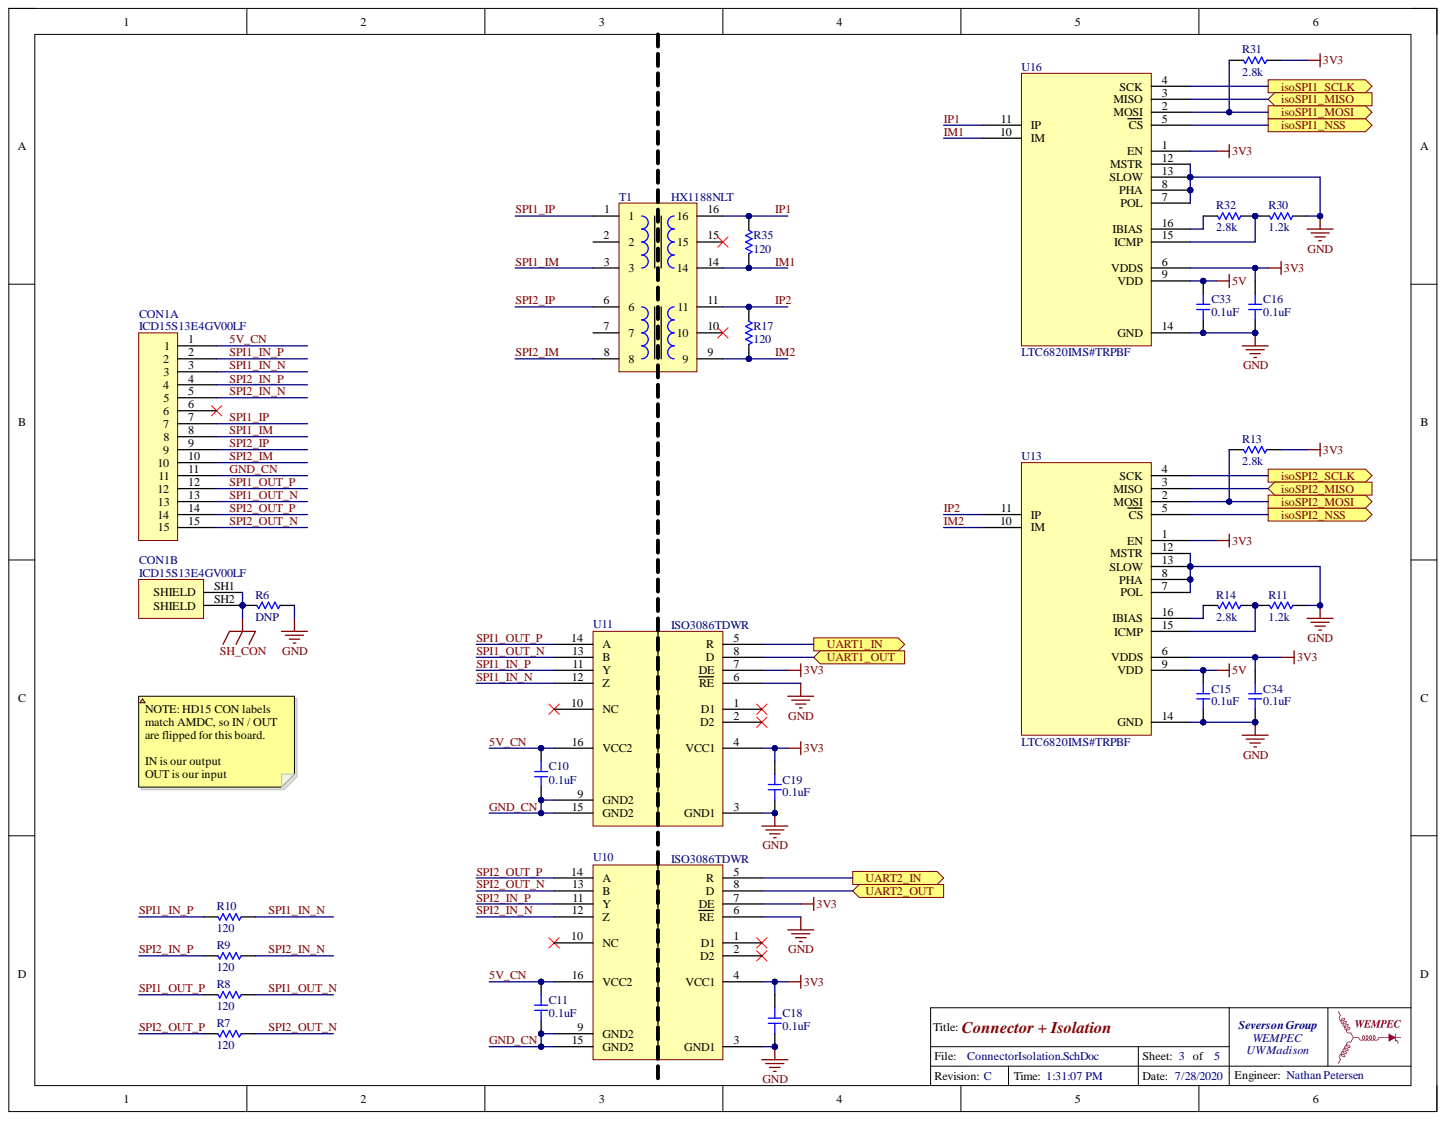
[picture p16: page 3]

NOTE: HD15 CON labels
match AMDC, so IN / OUT
are flipped for this board.

IN is our output
OUT is our input

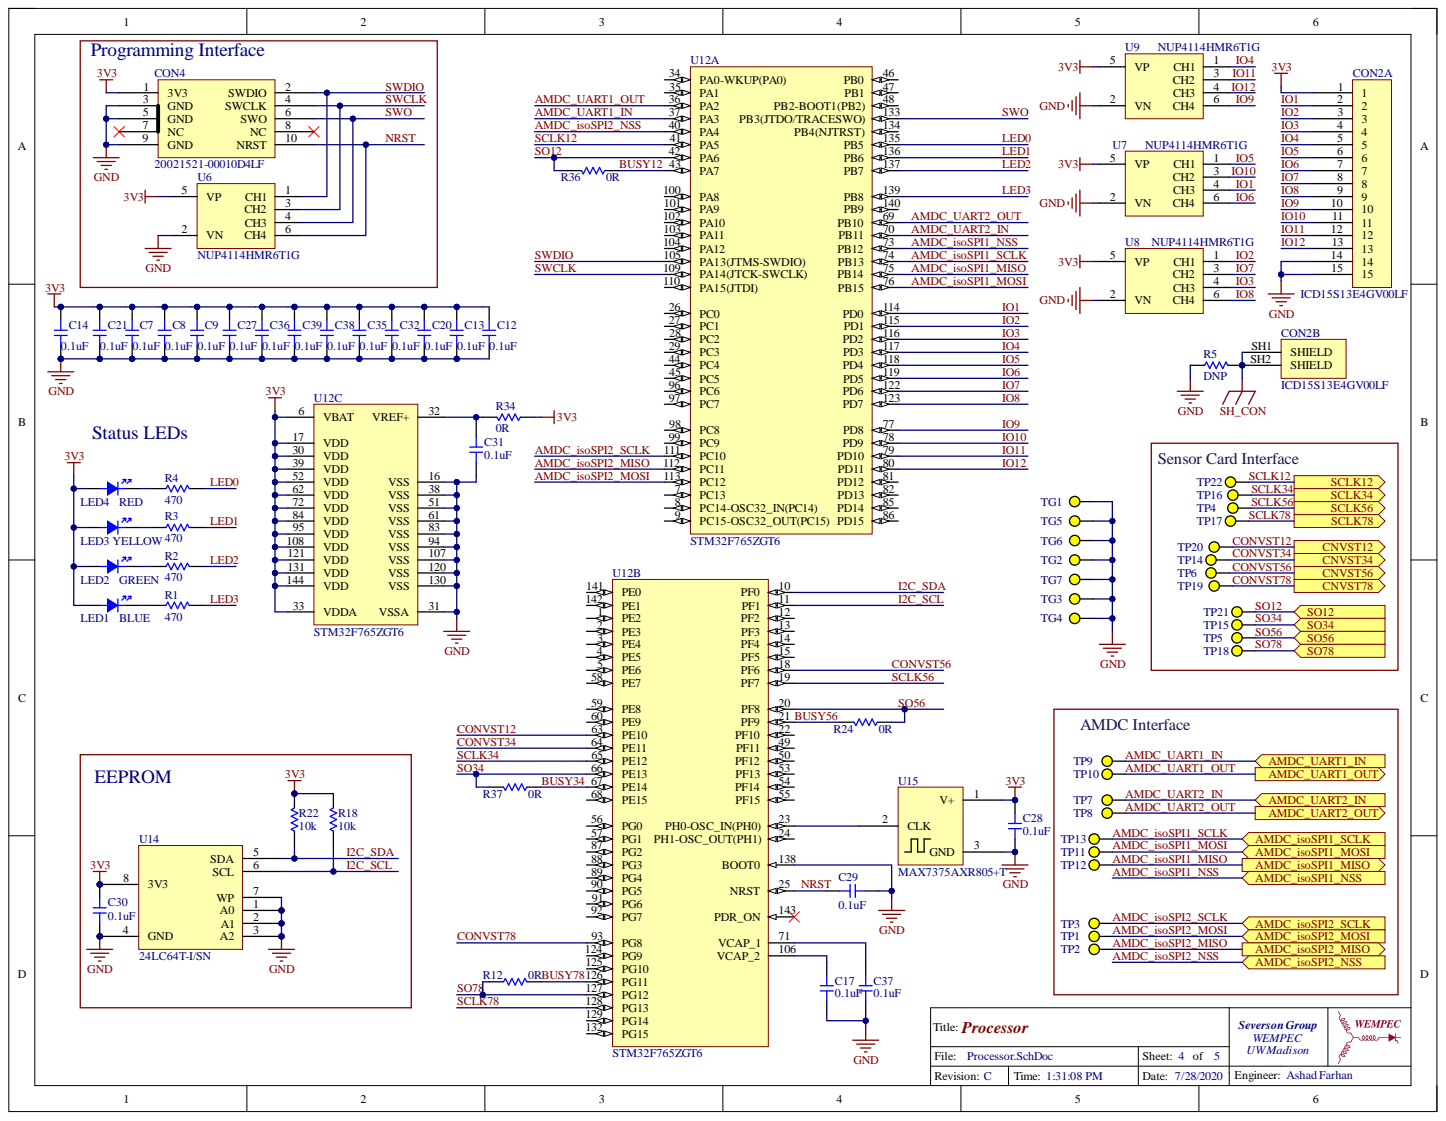
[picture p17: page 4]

I2C_SCL

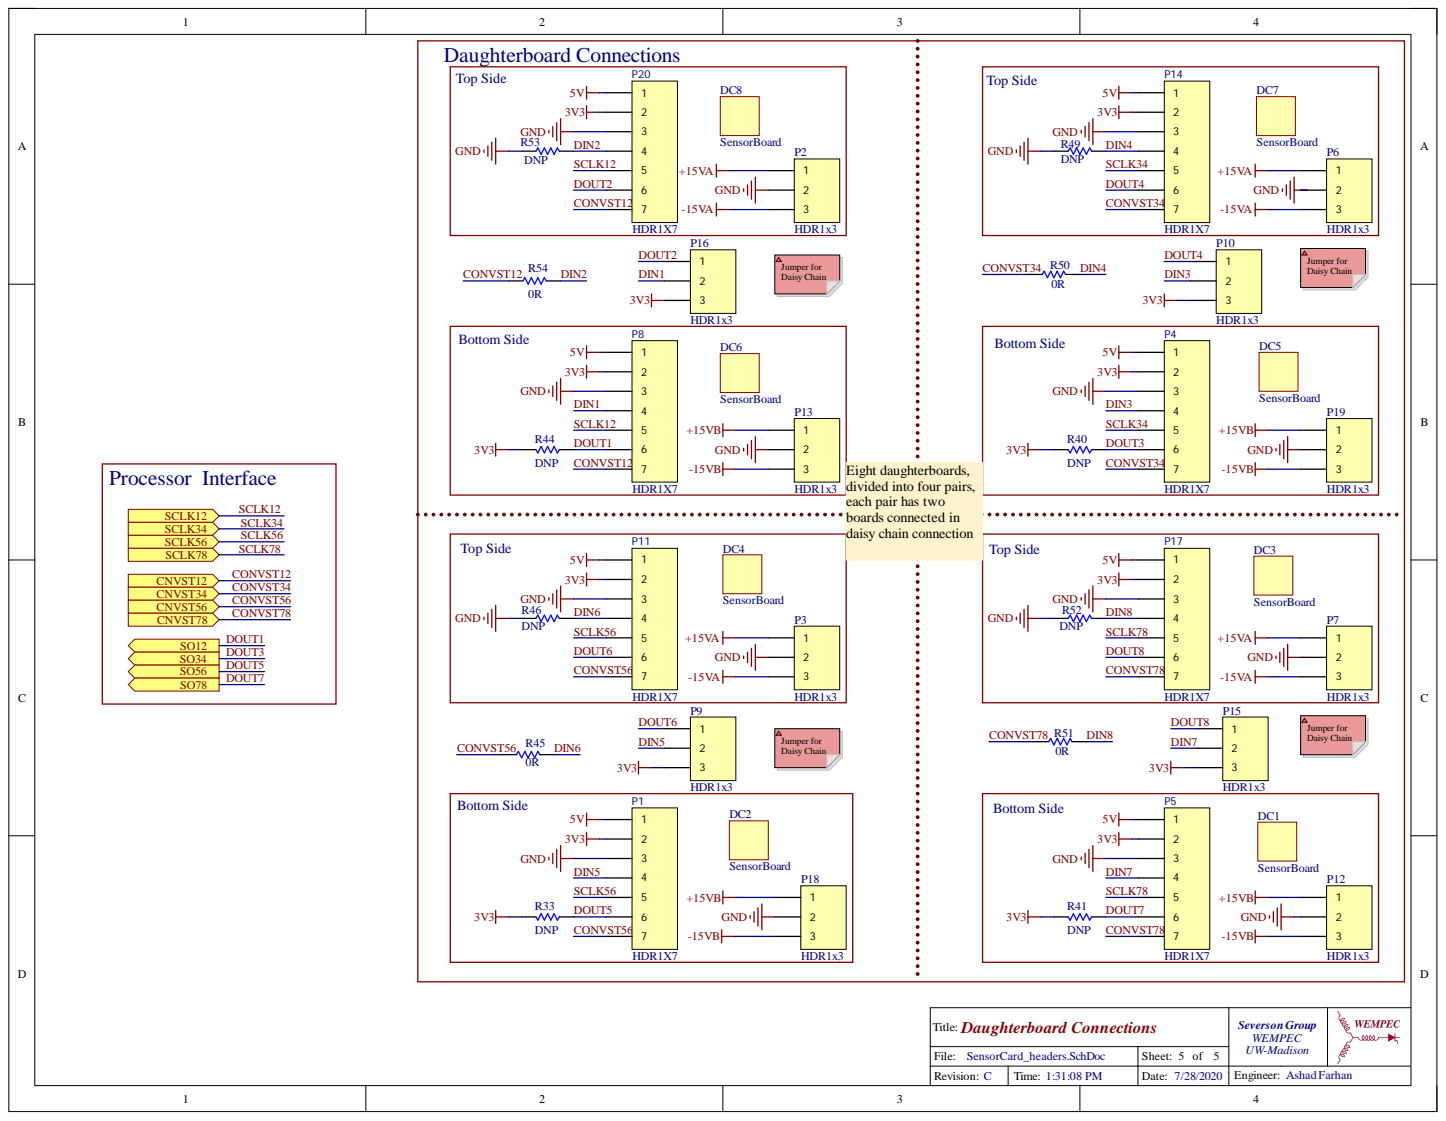
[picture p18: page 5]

Eight daughterboards,
divided into four pairs,
each pair has two
boards connected in
daisy chain connection

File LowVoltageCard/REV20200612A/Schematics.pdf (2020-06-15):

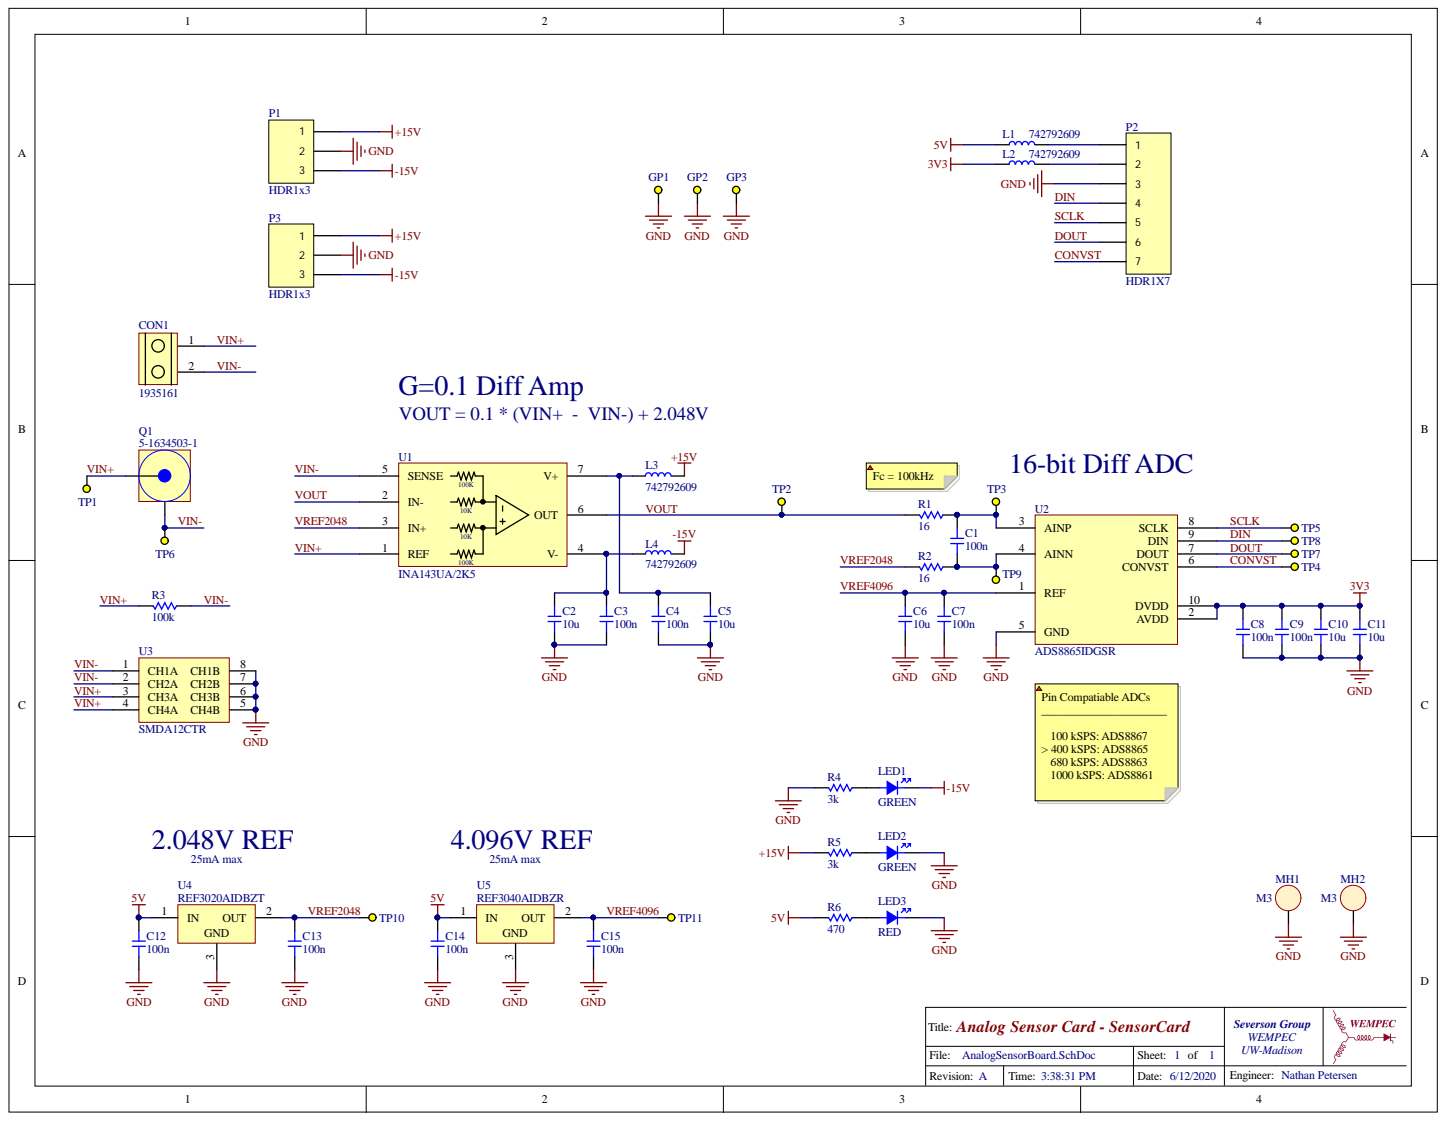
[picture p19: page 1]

Analog Sensor Card - SensorCard
Title:

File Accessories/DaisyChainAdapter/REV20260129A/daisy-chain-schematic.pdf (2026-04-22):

24V

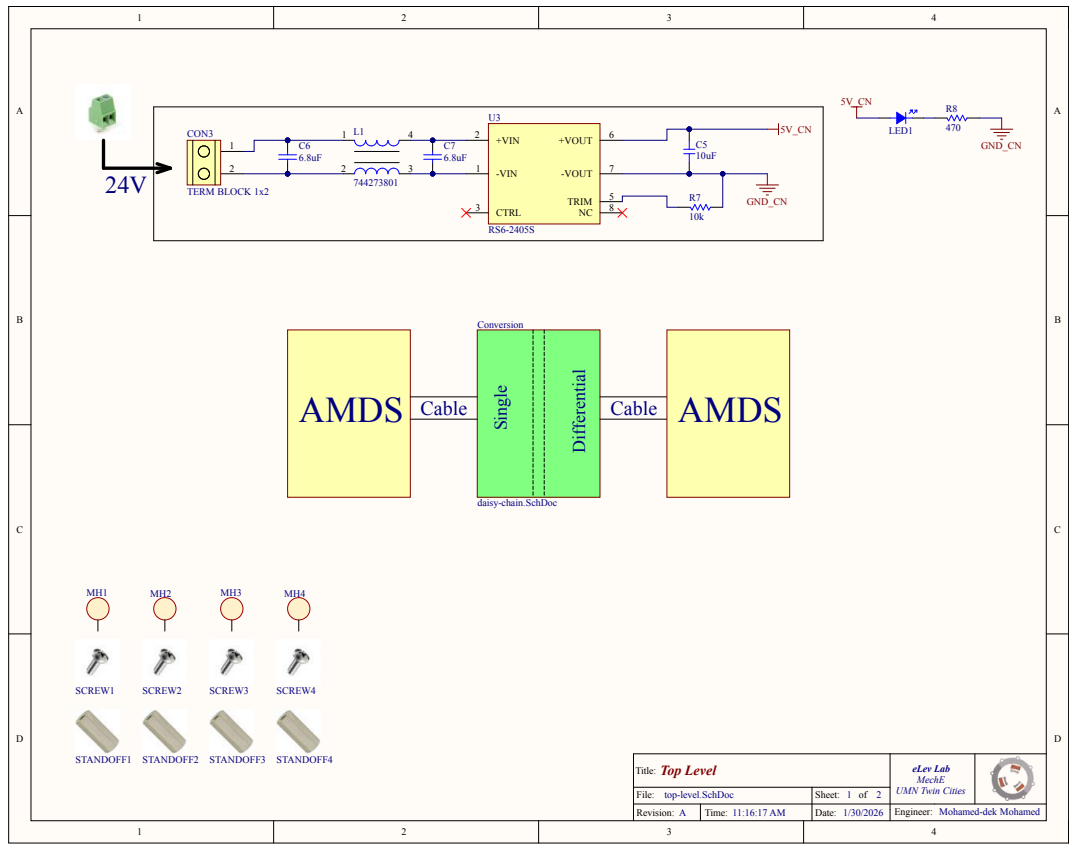
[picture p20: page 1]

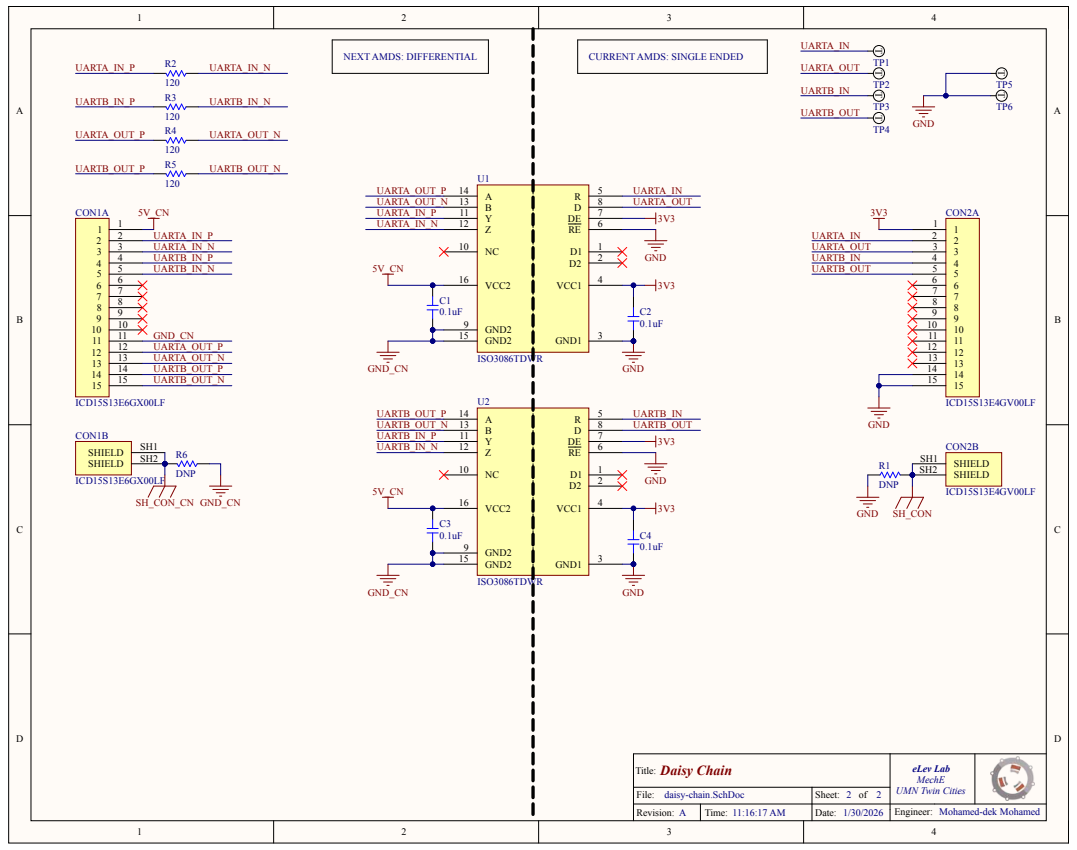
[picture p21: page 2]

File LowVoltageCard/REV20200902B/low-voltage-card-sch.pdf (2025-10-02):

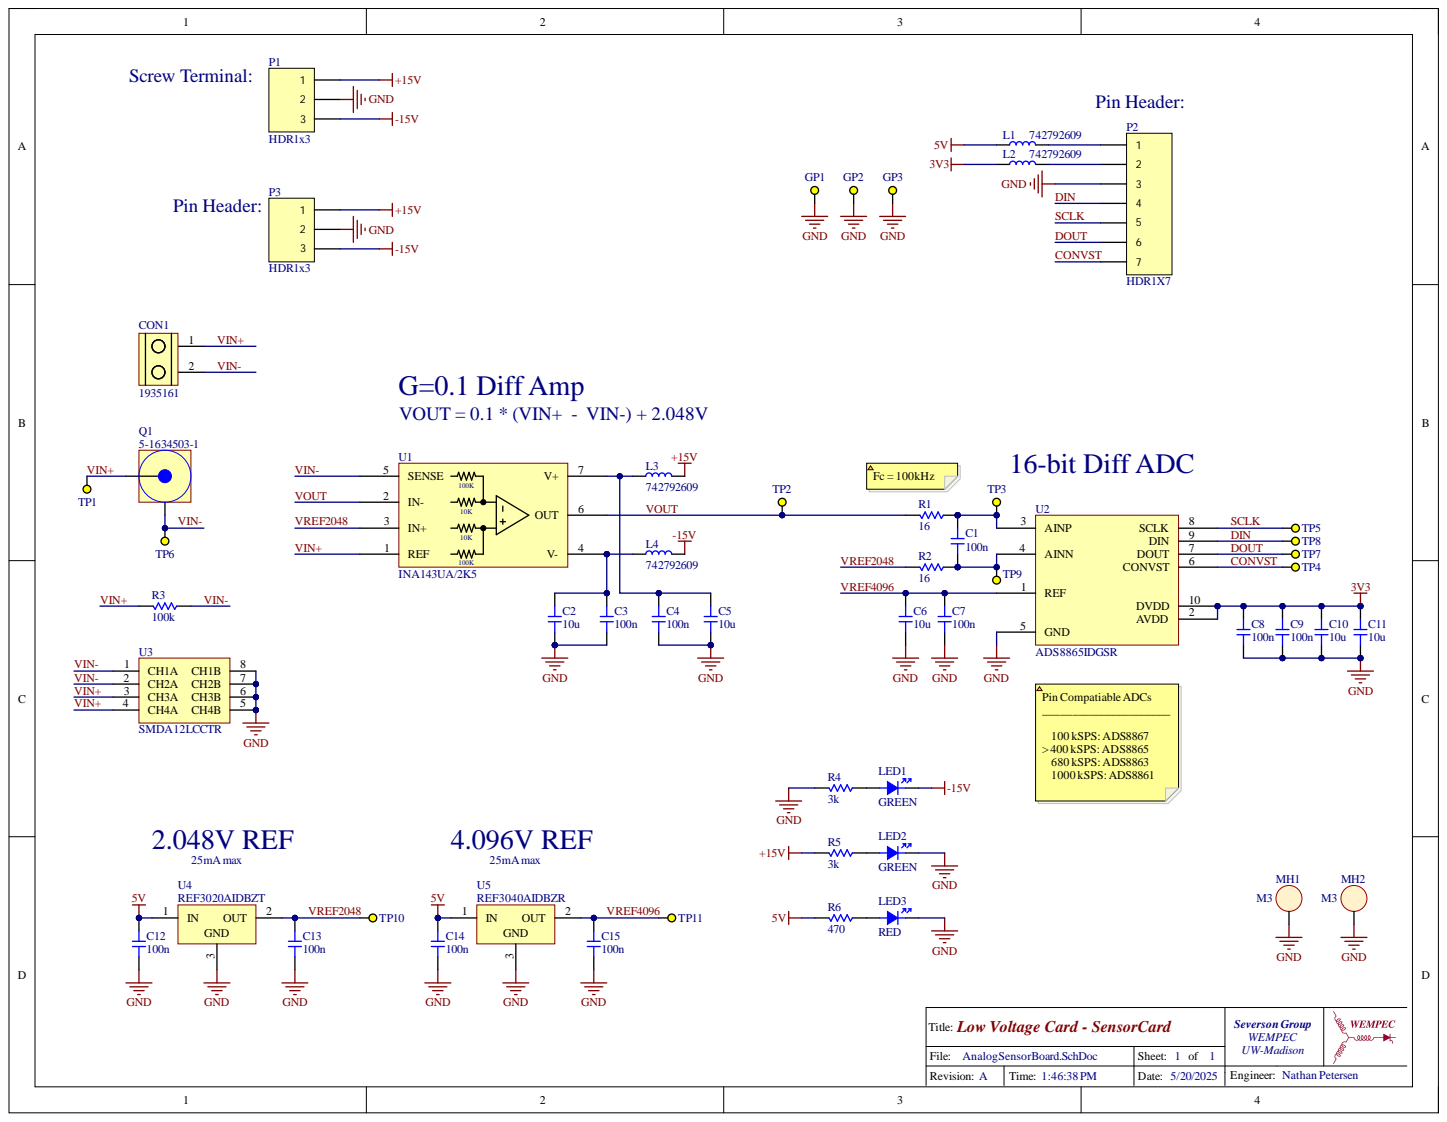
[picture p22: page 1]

Low Voltage Card - SensorCard
Title:

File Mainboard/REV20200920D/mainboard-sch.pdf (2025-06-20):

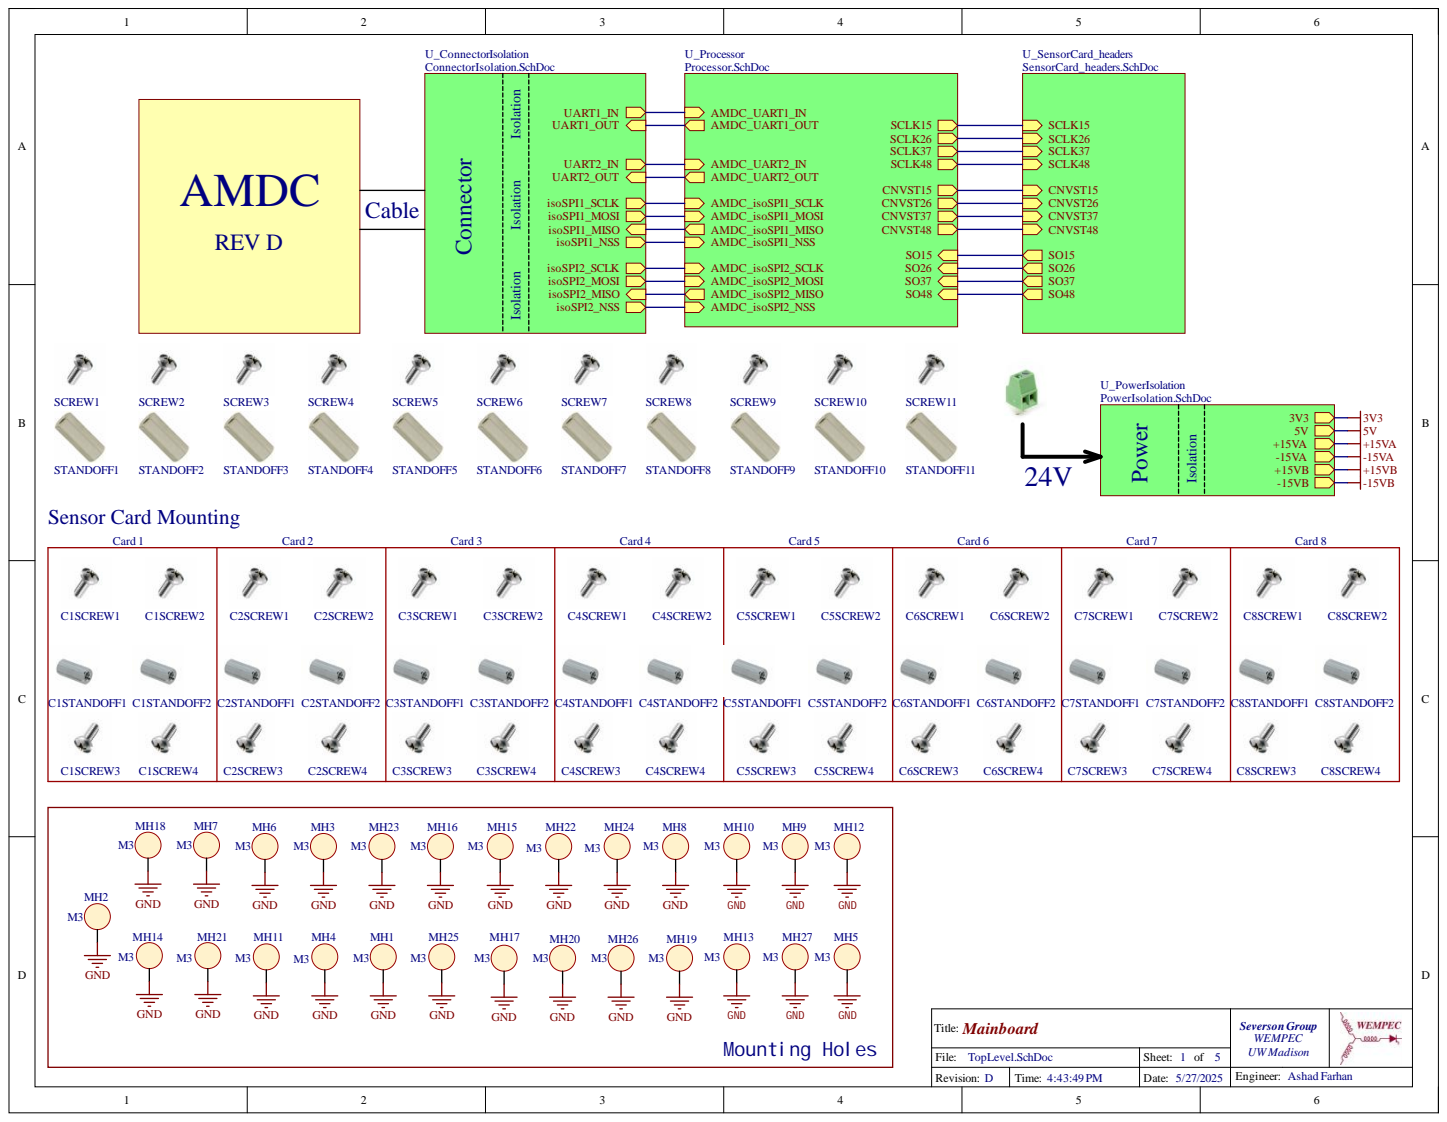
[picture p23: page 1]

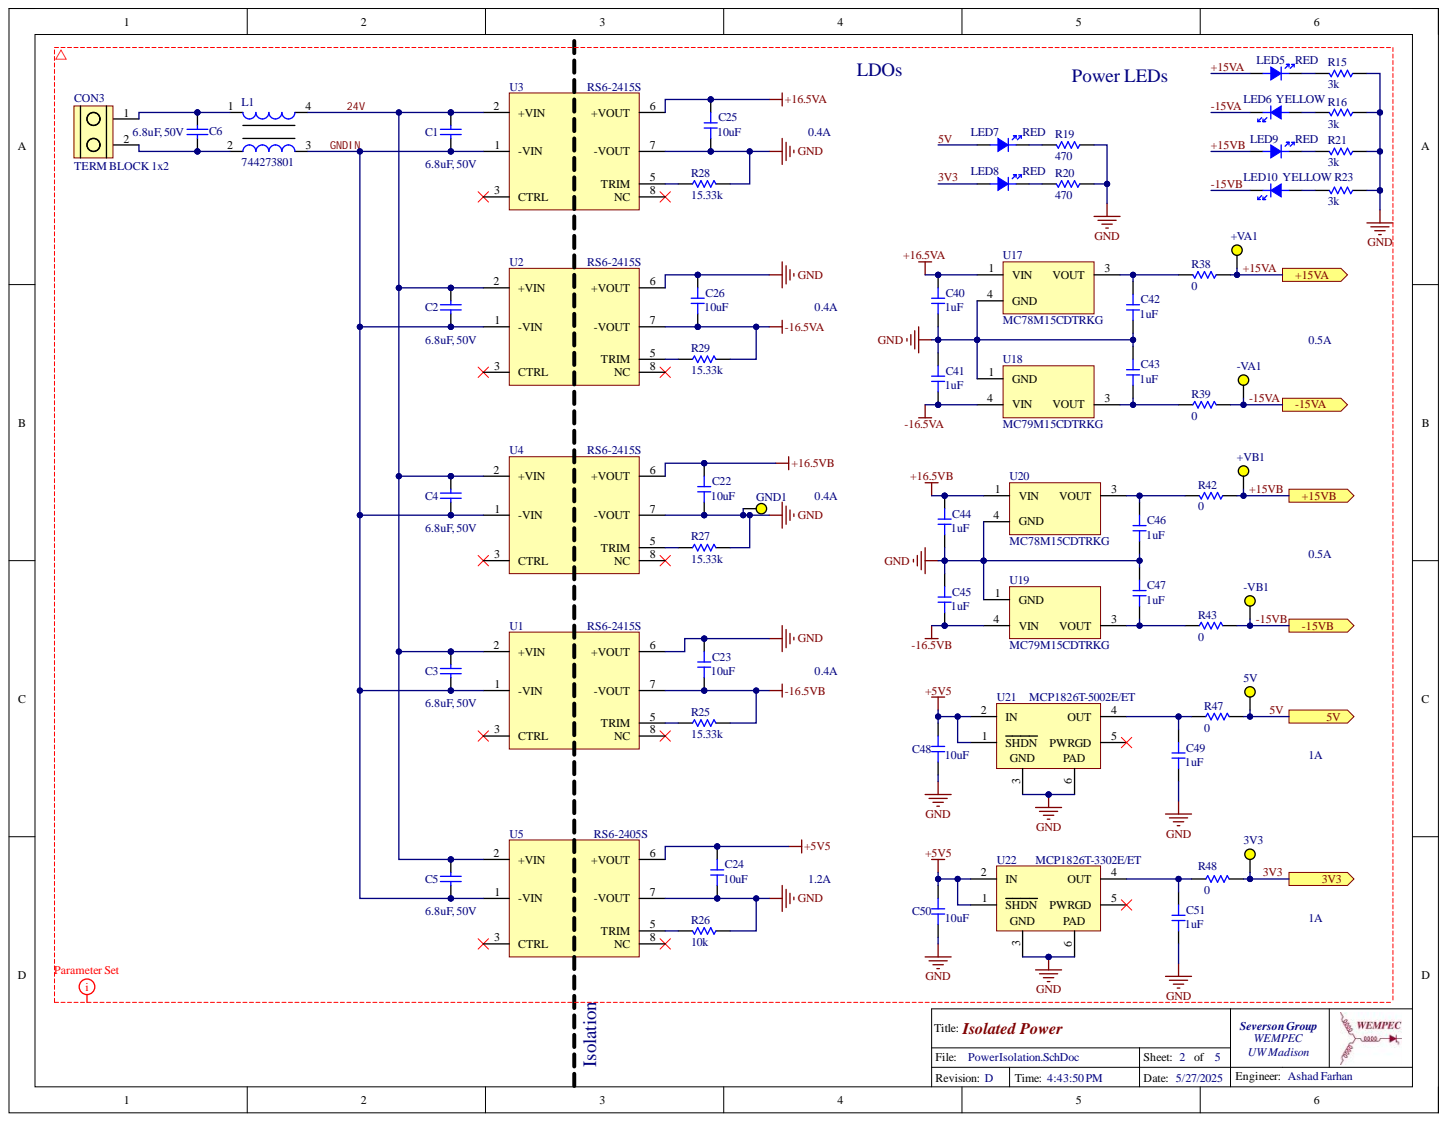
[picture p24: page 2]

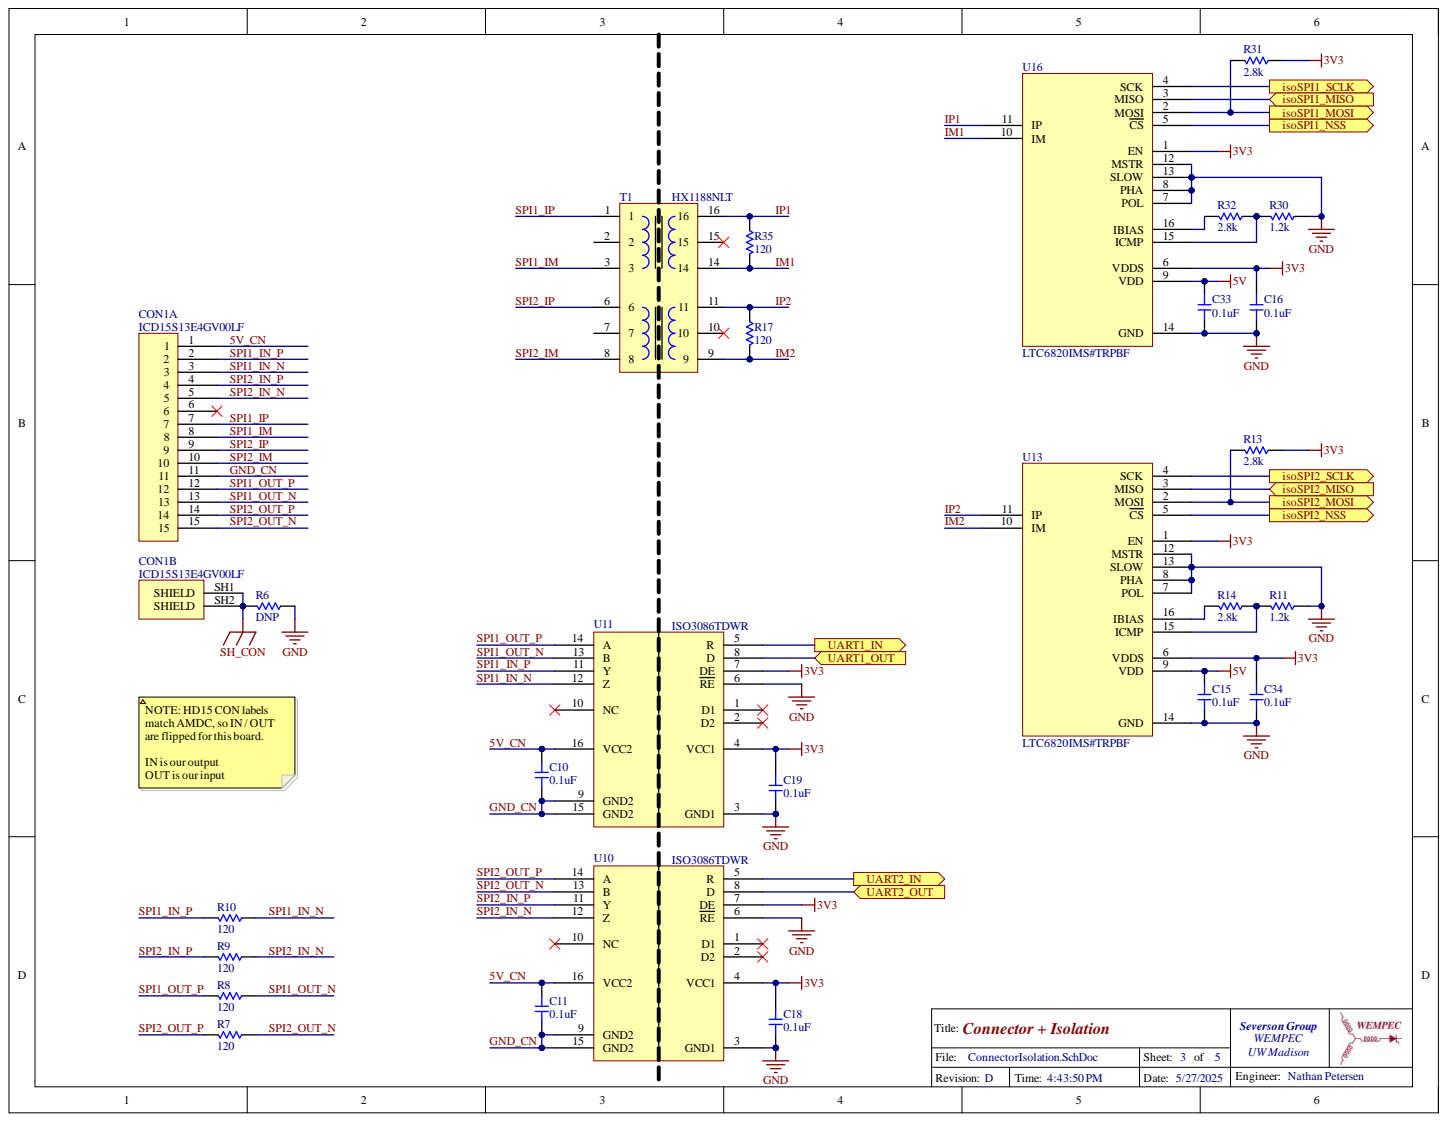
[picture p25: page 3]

NOTE: HD15CON labels
match AMDC, so IN / OUT
are flipped for this board.

IN is our output
OUT is our input


I2C_SCL


Eight sensor cards,
divided into four pairs,
each pair has two cards
connected in daisy
chain connection







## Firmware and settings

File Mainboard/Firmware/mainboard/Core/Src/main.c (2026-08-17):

// Drivers
#include "drv_clock.h"
#include "drv_gpio.h"
#include "drv_i2c.h"
#include "drv_led.h"
#include "drv_spi.h"
#include "drv_uart.h"
#include "platform.h"

// Modules
#include "adc.h"

int main(void)
{
    // Reset of all peripherals, Initializes the Flash interface and the Systick
    HAL_Init();

    // Configure the system clock
    drv_clock_init();

    // Initialize peripherals
    drv_spi_init();
    drv_uart_init();
    drv_led_init();

    // Initialize the main modules
    adc_init();

    uint8_t led = 0;

    // Use DWT cycle counter instead of HAL_GetTick()
    uint32_t ledDelta = DWT->CYCCNT;

    // Calculate how many CPU cycles are in 250ms.
    uint32_t cyclesPer250ms = SystemCoreClock / 4;

    // Disable the SysTick ISR
    //
    // The SysTick ISR causes jitter in the firmware operation,
    // and since this project does not use the SysTick features,
    // we do not need it to run during operation!
    //
    // Set bit 0 to 0
    SysTick->CTRL &= 0xFFFFFFFE;

    // Enable the Cortex-M7 DWT Cycle Counter for hardware delays
    CoreDebug->DEMCR |= CoreDebug_DEMCR_TRCENA_Msk;
    DWT->LAR = 0xC5ACCE55;
    DWT->CYCCNT = 0;
    DWT->CTRL |= DWT_CTRL_CYCCNTENA_Msk;

    // Infinite loop (all real work is done in ISRs)
    while (1) {
        // Handle LEDs using hardware cycle counts
        if (DWT->CYCCNT - ledDelta >= cyclesPer250ms) {
            ledDelta = DWT->CYCCNT;
            drv_led_clear();

            drv_led_on(1 << led);
            drv_led_display();

            if (++led >= DRV_LED_NUM_TOTAL) {
                led = 0;
            }
        }
    }
}

void HAL_MspInit(void)
{
    __HAL_RCC_PWR_CLK_ENABLE();
    __HAL_RCC_SYSCFG_CLK_ENABLE();
}

void SysTick_Handler(void)
{
    HAL_IncTick();
}

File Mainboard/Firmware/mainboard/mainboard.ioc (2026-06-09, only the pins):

Mcu.UserName=STM32F765ZGTx
PA13.Signal=SYS_JTMS-SWDIO
PA14.Signal=SYS_JTCK-SWCLK
PA15.Signal=SPI3_NSS
PA2.Signal=USART2_TX
PA3.Signal=USART2_RX
PA4.Signal=GPIO_Output
PA5.Signal=SPI1_SCK
PA6.Signal=SPI1_MISO
PA7.Signal=GPXTI7
PB10.Signal=USART3_TX
PB11.Signal=USART3_RX
PB12.Signal=SPI2_NSS
PB13.Signal=SPI2_SCK
PB14.Signal=SPI2_MISO
PB15.Signal=SPI2_MOSI
PB3.Signal=SYS_JTDO-SWO
PB5.Signal=GPIO_Output
PB6.Signal=GPIO_Output
PB7.Signal=GPIO_Output
PB8.Signal=GPIO_Output
PC10.Signal=SPI3_SCK
PC11.Signal=SPI3_MISO
PC12.Signal=SPI3_MOSI
PD0.Signal=GPIO_Output
PD1.Signal=GPIO_Output
PD10.Signal=GPIO_Output
PD11.Signal=GPIO_Output
PD2.Signal=GPIO_Output
PD3.Signal=GPIO_Output
PD4.Signal=GPIO_Output
PD5.Signal=GPIO_Output
PD6.Signal=GPIO_Output
PD7.Signal=GPIO_Output
PD8.Signal=GPIO_Output
PD9.Signal=GPIO_Output
PE10.Signal=GPIO_Output
PE11.Signal=GPIO_Output
PE12.Signal=SPI4_SCK
PE13.Signal=SPI4_MISO
PF0.Signal=I2C2_SDA
PF1.Signal=I2C2_SCL
PF6.Signal=GPIO_Output
PF7.Signal=SPI5_SCK
PF8.Signal=SPI5_MISO
PF9.Signal=GPXTI9
PG10.Signal=GPIO_Output
PG11.Signal=EVENTOUT
PG12.Signal=SPI6_MISO
PG13.Signal=SPI6_SCK
PG15.Signal=GPXTI15
PG8.Signal=GPIO_Output
PH0/OSC_IN.Signal=RCC_OSC_IN
PH1/OSC_OUT.Signal=RCC_OSC_OUT

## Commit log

2019-02-04 Initial altium files
    [CurrentSensors.SchDoc, Power.SchDoc, SensorCard.PcbLib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]
2019-08-24 add files for new measurement card. clean up repository.
    [CurrentSensors.SchDoc, Power.SchDoc, SensorCard.PcbLib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]
2019-08-24 add files for currentcard
    [CurrentSensorBoard.PcbDoc, CurrentSensorBoard.PrjPCB, CurrentSensorBoard.SchDoc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]
2019-08-26 add gerbers, bom to measurement card boards. updated legacy board altium files.
    [CurrentSensorBoard_BOM.xlsx, CurrentSensors.SchDoc, MeasurementCard.PcbDoc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]
2020-06-02 Initial commit of Analog Sensor board, direct copy from Current Sensor board
    [AnalogCard.PcbLib, AnalogCard.SchLib, AnalogSensorBoard.PcbDoc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]
2020-06-03 Finish design of board. This design was proposed to group
    [AnalogCard.PcbLib, AnalogCard.SchLib, AnalogSensorBoard.PcbDoc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]
2020-06-08 Routed board + implemented suggestions from design review. Ready to order.
    [AnalogCard.PcbLib, AnalogSensorBoard.PcbDoc, AnalogSensorBoard.SchDoc]
2020-06-12 Files for release
    [AnalogCard.PcbLib, AnalogCard.SchLib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]
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2020-07-29 Add copies of device datasheets
2020-07-29 Start working on SPI transactions
2020-07-31 Working drivers for ADCs and UART
2020-07-31 Optimize speed of ADC reading and UART data transmission
2020-08-01 Fully working system (10kHz TX + 100kHz ADC SYNC)
2020-08-01 Way faster UART tx (both lines in parallel, 6 usec for all data)
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2020-09-02 Motherboard REV C (#6)
    * Added Voltage card REV20190930C file, this has HV_Cleaacne of 2.286mm
    * Changed the revision number to REV20190930C in top_layer
    * PCB 3D mode, REV B changed to REV C
    * removed extra altium folders like history; updated PDF with REVC PDF
    * Add headers sheet for 8 sensor cards
    * Add the initial schematic for REVC
    * Update part numbers and clean up sensorcard headers
    * add extra isoSPI and change +-15V LDO
    * Rename and arrange designators
    * Change trim resistor to get 16.5V
    * Use one isolation for two isoSPI
    * replace 16.5V isolated converter for 1.1A rating
    * Revert to Previous commit
    * Add extra +/-15V converter for more current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
    [ConnectorIsolation.SchDoc, PowerIsolation.SchDoc, Processor.SchDoc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]
2020-09-02 Fix silkscreen labels for analog input + and -
    [AnalogSensorBoard.PcbDoc]
2020-09-02 Update part number in schematic for 3-pin header
    [AnalogSensorBoard.SchDoc]
2020-09-02 Add screws + standoffs to schematic for BOM to attach board to motherboard
    [AnalogSensorBoard.SchDoc]
2020-09-02 Update revision labeling and board name
    [AnalogSensorBoard.PcbDoc, AnalogSensorBoard.SchDoc]
2020-09-02 Update ESD device to one that is in stock
    [AnalogSensorBoard.SchDoc]
2020-09-02 Compile design for REV B
    [BOM_qty1.csv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]
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2020-09-04 Add pick place file in CSV format for PCBA
    [Pick_Place_for_AnalogSensorBoard.csv]
2020-09-24 Increased the HV clearance of Voltage sense board (#2)
    * add HV warning in PCB
    * update voltageCard repo structure
    * Create README.md
    * add volage bloc diagram
    * correct typo
    * rephrase sentence in readme.doc
    * Add readme, design details
    * update block diagram
    * correct typo
    * Fix link to docs subfolder
    * Update link to ADC datasheet
    * untent tht resistor pads
    * add PCB generated output
    * update pcb orderi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
    [SensorCard.PcbLib, SensorCard.SchLib, VoltageCard_bom_qty_10.xlsx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]
2020-09-24 Motherboard REVD PR (#26)
    * add latest files from REVD
    * Update readme to REVD
    * update to revd block diagram
    * update reference to REVD diagram
    * update block-dia
    * change rev number
    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
    [ConnectorIsolation.SchDoc, PowerIsolation.SchDoc, Processor.SchDoc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]
2020-10-06 Current card revision (#20)
    * Update schematic
    * Add 3D image of the pcb
    * Add gerber files
    * Add the bill of materials
    * Add initial documentation
    * Update schematic title block
    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
    [CurrentSensorBoard.GBL, CurrentSensorBoard.GBO, CurrentSensorBoard.GBP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]
2020-10-12 add screws standoff in BoM
    [SensorMotherBoard_BOM.xlsx]
2020-10-12 add pick and place file
    [Pick Place for SensorMotherBoard.csv]
2020-10-12 remove spaces in file names
    [Pick_Place_for_SensorMotherBoard.csv]
2020-10-12 change BOM to csv format
    [SensorMotherBoard_BOM.csv, SensorMotherBoard_BOM.xlsx]
2020-10-13 add note on standoffs and correct typo
2020-10-13 Rename BOM file
    [SensorMotherBoard_BOM_10qty.csv]
2021-01-04 Update voltage card documentation (#29)
    * Add 3D view of the PCB
    * Add 3D view of PCB to documentation
    * Update README.md
    * Update README.md
    * Update README.md
    * Update README.md
    * Update block diagram
    * Add opamp stage schematic
    * Update README.md
    * Update README.md
    * Update README.md
    * Update README.md
    * Update README.md
    * Update README.md
    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
2021-01-06 Update naming (#30)
    * Update naming convention
    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
    [AnalogCard.PcbLib, AnalogCard.SchLib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]
2021-01-19 Update repository (#31)
    * Add current card altium files
    * Add 3D image of AMDS system
    * Update location of the current card datasheets
    * Update links to the current card datasheets
    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
    [CurrentSensorBoard.PcbDoc, CurrentSensorBoard.PrjPCB, CurrentSensorBoard.SchDoc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]
2024-09-16 Release v2.0.0 (#52)
    * Alternative Processor Firmware Update Process
    Added instructions for creation of a new project targeting the alternative processor all new AMDS mainboards are populated with.
    * Add Compiler Optimization instructions to README
    * Modify TX code to remove SYNC_TX interrupt
    * Update main and adc code for new transmit behaviour
    * Replace obselete type to fix build error
    * Remove adc_ignore_next_sample(), no longer necessary
    * Disable the SysTick ISR
    * Replace ping-pong adc data buffers with single buffer
    ---------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
    [adc.c, main.c]
2025-04-14 AMDS-REVD mainboard BOM update only (#56)
    * Update the AMDS-REVD mainboard docs and BOM to account for just 1 board
    * Separate out board parameter and assembly parameter tables
    * Clean up tables and update fields to correct values.
    ---------
    [SensorMotherBoard_BOM_10qty.csv, mainboard-bom.csv]
2025-04-17 AMDS REV20200920D dash-case naming update (#58)
    * renames files in AMDS REVD to dash-case
    * Rename Schematic.pdf to schematic.pdf
    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
    [pick-place-for-sensor-mainboard.csv]
2025-04-26 Update bom column order
    [mainboard-bom.csv]
2025-05-02 revert bom changes
    [mainboard-bom.csv]
2025-05-02 reverted changes to pick and place, but kept formatting
    [pick-place-for-sensor-mainboard.csv]
2025-05-02 update BOM to agree with pick & place
    [mainboard-bom.csv]
2025-05-02 R5 and R6 are placed
    [mainboard-bom.csv]
2025-05-06 R5 and R6 as DNP for both BOM and pick-and-place
    [mainboard-bom.csv, pick-place-for-sensor-mainboard.csv]
2025-05-08 Add PCB Layers PDF to the AMDS REVD release folder (#66)
    * add pcb-layers pdf to revd folder
    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
2025-06-13 Update Current Card Release Files (#73)
    * update current card folder
    * update readme
    * fixe relative link to mainboard readme
    * revert unwated altium changes
    * delete Gerbers
    * add renamed gerbers folder
    * update name
    * update mention of the mounting screws
    * Update current-sensor-bom.csv
    * update p1 and p3
    * Update current-sensor-bom.csv
    [CurrentSensorBoard.GBL, CurrentSensorBoard.GBO, CurrentSensorBoard.GBP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]
2025-06-20 Update High Voltage Card Release Files (#74)
    * update folder
    * update relative link
    * update readme and naming
    * add bom section to readme
    * Update naming in readme and values
    * Add revision to readme title
    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
    [VoltageCard_bom_qty_10.xlsx, VoltageSensorBoard.SchDoc, high-voltage-sensor-bom.csv]
2025-06-20 Update schematic and BOM to include screws and standoffs (#76)
    * Update schematic and BOM to include screws and standoffs
    * Update sensor card naming and standoffs for mounting
    * update standoff in bom
    * add 3d pdf and rename schematic
    * fix csv lint
    * update screw
    * update readme to mention sensor card mounting
    * update schematic layout and BOM
    * compress the schematic file
    * revert unnecessary changes
    * revert unnecessary changes
    * revert unnecessary changes
    * fix incorrect header part number
    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
    [ConnectorIsolation.SchDoc, PowerIsolation.SchDoc, Processor.SchDoc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]
2025-10-02 Update Low Voltage Card Release Files (#75)
    * update file naming convention
    * update release README to match template
    * update mention of the mounting screws to match other sensor cards
    * update low-voltage-card-bom.csv to match template
    [AnalogSensorBoard.SchDoc, BOM_qty1.csv, low-voltage-card-bom.csv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]
2026-04-22 Add Daisy Chain Adapter Board (#82)
    * add initial readme files
    * add intial altium project files
    * change name of the schematic file
    * update the schematic to most recent changes
    * update title block on toplevel schematic
    * add part numbers to test points
    * add current pcb and pcblib
    * update capacitor comments to follow C5
    * remove mention of pcb in schematic branch
    * update IO ports for daisy chaining
    * link pcb and pcblib
    * update schematics to match sch branch
    * fix some drc issues
    * fix design rule issues
    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
    [daisy-chain-bom.csv, daisy-chain.PrjPcb, daisy-chain.SchDoc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]
2026-06-05 Setup gh actions integration (#126)
    * Add gh actions
    * Make files executable
    * Run check-format as root
    Updated script execution to use sudo for clang-format and check-format.
    * Update old gh-actions integration
    * Use old gh-actions
    * Update GitHub Actions workflow for formatting checks
    * Change llvm version
    * Update check-format.yml
    * Update check-format.yml
    * Update check-format.yml
    * Update clang-format
    * Fix formatting
    * Fix formatting
    [main.c]
2026-06-09 Add AMDS firmware changes to implement the DCP (#102)
    * add firmware to propogate sync signal
    * add first attempt at implementing queue
    * add new partial DMA implementation
    * add all code for dma useage
    * add currently working daisy chain firmware
    * add transmit firmware for channels 97 through 9B
    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
2026-07-02 Swap FBC USART channels
    [drv_uart.c]
2026-08-17 Rework AMDS daisy chain implementation (#140)
    * Optimize transmission
    * Remove IRQ during sample/transmit
    * Add AMDS implementation
    * Accelerate AMDS communication
    * Cleanup code
    * Format code
    * Cleanup unused code
    Removed unused NOP macros and updated comment for wait_cycles calculation.
    * Cleanup unused code
    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
    [adc.c, drv_uart.c, main.c]
